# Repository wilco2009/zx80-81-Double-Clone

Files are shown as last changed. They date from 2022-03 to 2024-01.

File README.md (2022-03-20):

# PROJECT DOUBLE CLON ZX80/ZX81

Reading the works of [Grant Searle](http://searle.x10host.com/#ZX80), I have decided to start with the project to build a full computer to understand in depth his functionality. What can be more proper that a ZX80 totally based in discrete chips? 

In my spare time, I have started to work on it and you can find the results in the following lines.

I have copyied the schematics from the original zx80, and have made some modifications on it.

- I have added the extra circuitery to generate /NMI signal (Grant Searle Schematics), making possible to have two machines in one, by selecting it through a switch.
- Original 1K RAM in two chips have been replaced by one SRAM chip of  32KB.
- Original 4K ROM have been replaced by a EEPROM of 32KB. It necesary to store both ROMs (ZX80/ZX81) and it is cheaper than other smaller EPROMs.
-  RF modulator have been removed and replaced by a circuit to generate the standard back porch, missing in the original ZX80 PAL signal.

ZX80/81 Clone

The final result is nor a exact copy of the original as the case of Grant, but the board match accurately in the original case, and I very happy with the result.

## TECHNICAL & ASSEMBLY INFORMATION

In this project you can find the necesary information to build your own zx80. I think the most funny way to obtain your clon is to do it from zero, but if you wanna a clon and need the PCB or you have not enough knowledge or experience to assembly it, I have some spare PCBs and componentes, and I can sell them or assembly the clon for you. Please feel free to contact me and I'm sure we can reach an agreenment. ;)

Current version: 1.1

![](https://lh3.googleusercontent.com/rCJV6tn4bRtD5xP2J01XtbQhOAFcQkIHwjG2PTs5kUFLTJYEPpwRD9dPU9Wus_7P2roRMrFiV_r6bx4AB1eH3hhHG4VBcHm-jtsIfwT51LC9u5qDKVhMcgAC-uYpSRKtiEv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)

## JUMPER POSITION
JP1: RAMOE, Not relevant but must be present in one position
JP2:
              1-2 - Inverse Video
              2-3 - Standard Video
S2: ZX80/81 Mode selection (If you use external selection from the expansion board this jumper have to be removed)
              1-2 - ZX81 mode
              2-3 - ZX80 mode.

S4: Function of the Pin23B in the expansion bus. 
In original ZX80 pin 23B of the expansion bus is spare, but in a ZX81 PIN23B is use as /ROMCS signal.
If you want to use external zx81 mode selection form the expansion board you have to use position 1-2. In this case (in zx81 mode) cards replacing the internal ROM will not works.
If you prefer to use this kind of cards, you have to wire the zx81 selector (S2) directly to an accesible switch and set S4 in 2-3 position (remember to remove JP1 in the expansion board)
              1-2 - ZX81/ZX80 mode selection in PIN 23B
              2-3 - /ROMOE in PIN 23B

### Back porch Grant Searle solution:

              JP3 = 2-3
              JP5 = OFF
              JP6 = 1-2

### Back porch generation José Leandro solution:
              Adjust image with R37 & R33
              JP3 = 1-2
              JP5 = ON
              JP6 = 2-3

### Without Backporch generation (original ZX80 video)
              JP3 = 1-2
              JP5 = OFF
              JP6 = 1-2
              
## EXPANSION BOARD

This board has double functionality, first leaves enough room to connect zx81 cards  without trip with the video connector, and by other hand adds some extra functionality to the main board.


Expansion board let you to supply power to the computer with a miniUSB charger. If you plan to use external cards using 9V you will must to connect the computer to a 9V PS through the standard conector.
If you use the miniUSB supply, you could use the ON/OFF switch present in the board (S1) to turn on the computer.
S2 is a reset button, and it will works in any case.
JP7 Lets you to select ZX80/81 mode from the board if the position of the main jumper S4 is 1-2 and JP1 in the expansion board is ON.

JP1 Lets you aisle pin23B in the computer from the JP7 selector. It must be OFF if computer jumper S4 is 2-3.

![Clon working together with the ZXBlast](https://lh3.googleusercontent.com/j9ALMYmShmvCE-jy-AzifAf2zu_0noKhuHjYqihIMtmODiZwof2czWIUYXH-UqWGO6TdXiLnMDjAKpj7Po1c5WaS6kIWaJdyXEqjynNArSz48OjEJksTGsXhDxQqEvnr6YD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)

CONTACT: wilcoavs at gmail dot com



Update 01/02/2020.
Fix to resolve an incompatibility with some 74LS00s who inverts the screen. It is necessary to insert a 47K resistor between pin 1 and pin 14 of IC 11.

Update 17/02/2021 (many thanks to Augusto Baffa)
Quoted Augusto Baffa:
"My signal clock from IC18 PIN 9 was about (0-3v) and the High Pass Filter created by R25 and C11 was about (0-1v). It works on IC16 PIN 9 to generate the pulse that loads S/L on IC9 PIN 1 but was not working to load the latch'd on normal/inverse circuit 'cos IC11 pin 3 was always high.

So, after some testing I found that it's necessary to use another high pass filter to feed IC11 PIN2. I'm using a 100pF capacitor and a 3k6 resistor. After that it works fine. 



there is another item that could be improved. I've tested the Ear/cassete interface and it's producing a very low signal to IC10 PIN2.
 I analyzed the circuit on proteus and compared with original zx81 schematics and get the following:

Blue signal (it's dark... sorry)  is the signal produced by the original Searle's version. The red one is my propose in order to use the same PCB holes. and the green is the signal produced by the original zx81 circuit."



https://wilco2009.blogspot.com/2017/07/project-double-clon-zx80zx81-reading.html

## ACKNOLEDGEMENTS
- Jim Westwood - For designing the original machine
- Clive Sinclair - For introducing me in the computers world.
- Grant Searle - For his excellent work, he was the origin of mine. 
- Jose_Leandro, habbisoft - (in special way to jose_leandro) For helpping me in de debugging phase
- alvaroalea - For create an amaizing 3d printed case.
- carmeloco,flopping,sinclair200 - for supporting me in the initial phase

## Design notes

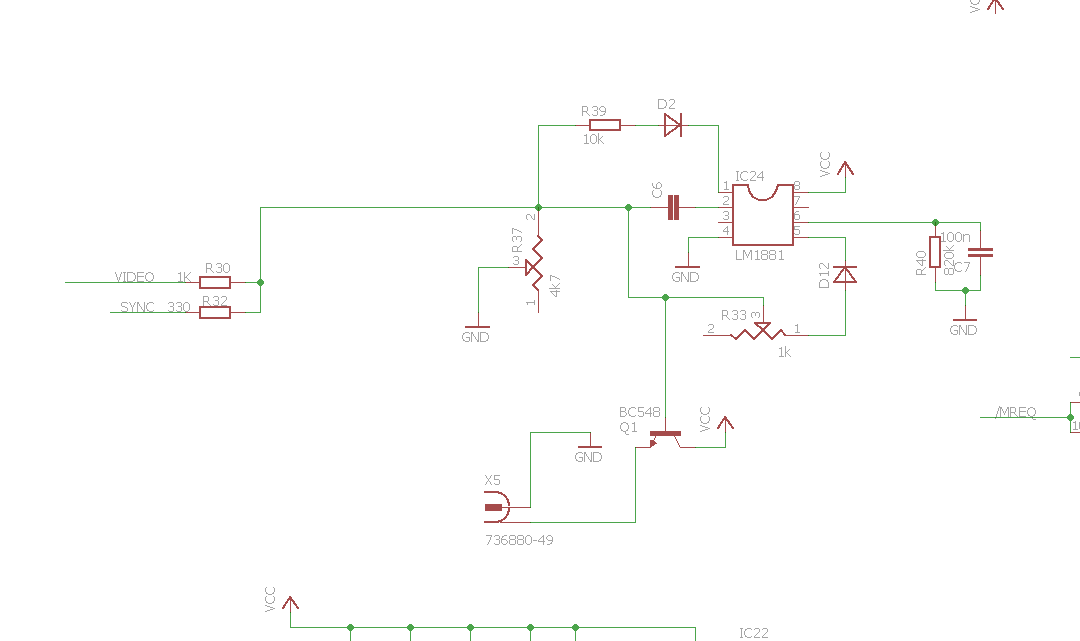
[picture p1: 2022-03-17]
doc/mod de video.png

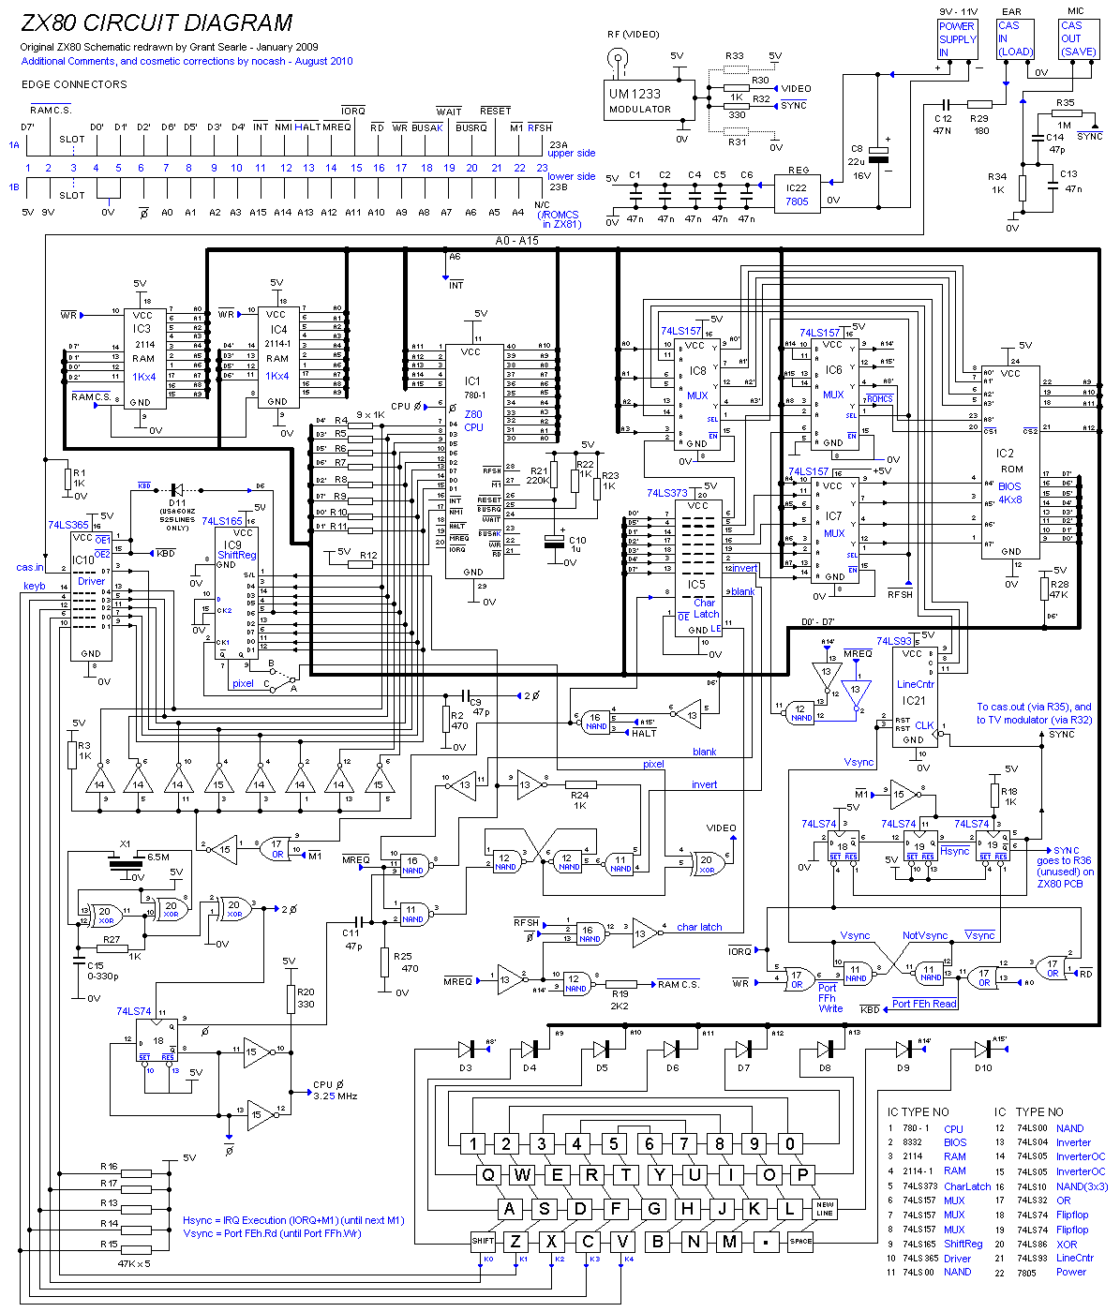
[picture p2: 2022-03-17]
doc/zx80-sch (original).gif

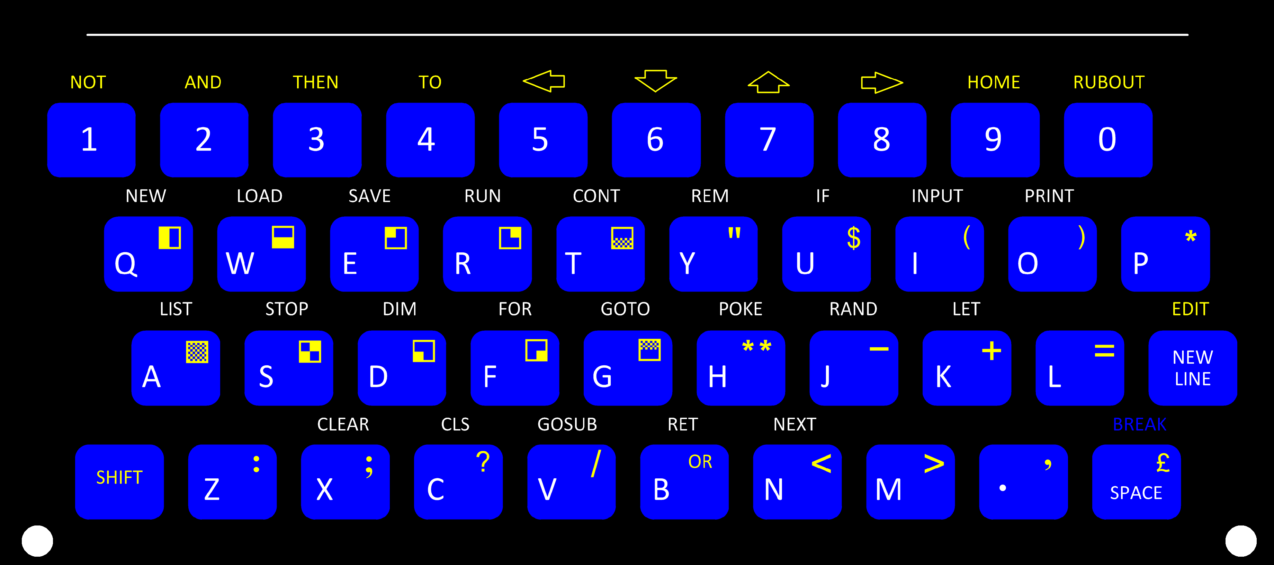
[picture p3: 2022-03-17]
Labels/Keyboard - zx80.png

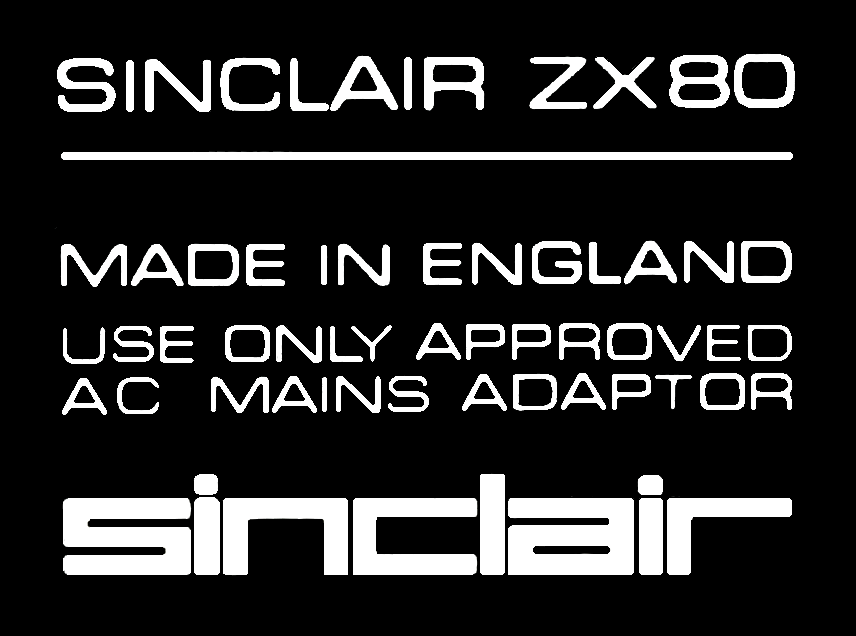
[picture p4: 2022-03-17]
Labels/made in england.png

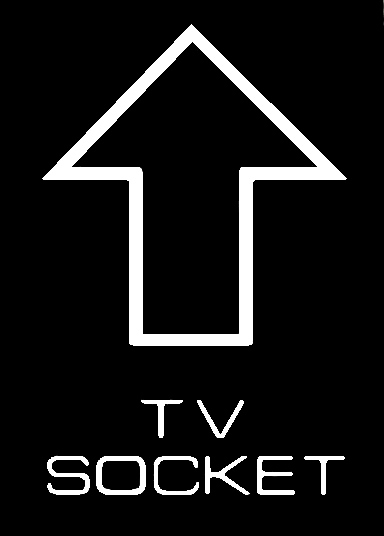
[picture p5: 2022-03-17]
Labels/tv socket.png

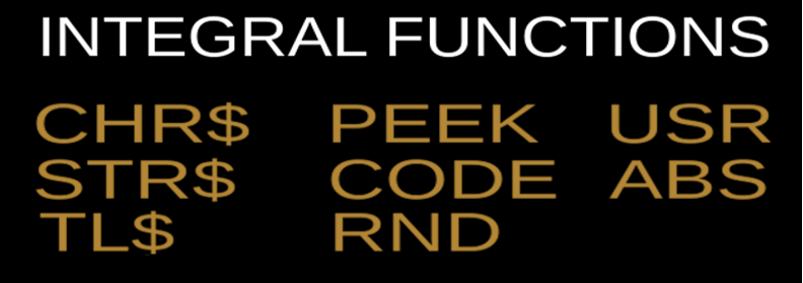
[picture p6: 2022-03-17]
Labels/ZX80 FUNCTIONS.png

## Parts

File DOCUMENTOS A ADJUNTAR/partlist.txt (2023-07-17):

Partlist

Exported from zx80_build039.routed.brd at 14/05/2023 19:09

EAGLE Version 9.6.2 Copyright (c) 1988-2020 Autodesk, Inc.

Assembly variant: 

Part     Value          Package      Library        Position (mm)         Orientation

.        TA_DK          TA_DK        dome-key       (124.46 10.16)        R0
1        TA_DK          TA_DK        dome-key       (10.16 52.705)        R0
1A                      EDGEPIN      wirepad        (10.16 200.025)       R0
1B                      EDGEPIN      wirepad        (10.16 200.025)       MR0
2        TA_DK          TA_DK        dome-key       (23.8125 52.705)      R0
2A                      EDGEPIN      wirepad        (12.7 200.025)        R0
2B                      EDGEPIN      wirepad        (12.7 200.025)        MR0
3        TA_DK          TA_DK        dome-key       (38.1 52.705)         R0
4        TA_DK          TA_DK        dome-key       (52.07 52.705)        R0
4A                      EDGEPIN      wirepad        (17.78 200.025)       R0
4B                      EDGEPIN      wirepad        (17.78 200.025)       MR0
5        TA_DK          TA_DK        dome-key       (66.04 52.705)        R0
5A                      EDGEPIN      wirepad        (20.32 200.025)       R0
5B                      EDGEPIN      wirepad        (20.32 200.025)       MR0
6        TA_DK          TA_DK        dome-key       (80.01 52.705)        R0
6A                      EDGEPIN      wirepad        (22.86 200.025)       R0
6B                      EDGEPIN      wirepad        (22.86 200.025)       MR0
7        TA_DK          TA_DK        dome-key       (93.98 52.705)        R0
7A                      EDGEPIN      wirepad        (25.4 200.025)        R0
7B                      EDGEPIN      wirepad        (25.4 200.025)        MR0
8        TA_DK          TA_DK        dome-key       (107.95 52.705)       R0
8A                      EDGEPIN      wirepad        (27.94 200.025)       R0
8B                      EDGEPIN      wirepad        (27.94 200.025)       MR0
9        TA_DK          TA_DK        dome-key       (121.92 52.705)       R0
9A                      EDGEPIN      wirepad        (30.48 200.025)       R0
9B                      EDGEPIN      wirepad        (30.48 200.025)       MR0
10A                     EDGEPIN      wirepad        (33.02 200.025)       R0
10B                     EDGEPIN      wirepad        (33.02 200.025)       MR0
11A                     EDGEPIN      wirepad        (35.56 200.025)       R0
11B                     EDGEPIN      wirepad        (35.56 200.025)       MR0
12A                     EDGEPIN      wirepad        (38.1 200.025)        R0
12B                     EDGEPIN      wirepad        (38.1 200.025)        MR0
13A                     EDGEPIN      wirepad        (40.64 200.025)       R0
13B                     EDGEPIN      wirepad        (40.64 200.025)       MR0
14A                     EDGEPIN      wirepad        (43.18 200.025)       R0
14B                     EDGEPIN      wirepad        (43.18 200.025)       MR0
15A                     EDGEPIN      wirepad        (45.72 200.025)       R0
15B                     EDGEPIN      wirepad        (45.72 200.025)       MR0
16A                     EDGEPIN      wirepad        (48.26 200.025)       R0
16B                     EDGEPIN      wirepad        (48.26 200.025)       MR0
17A                     EDGEPIN      wirepad        (50.8 200.025)        R0
17B                     EDGEPIN      wirepad        (50.8 200.025)        MR0
18A                     EDGEPIN      wirepad        (53.34 200.025)       R0
18B                     EDGEPIN      wirepad        (53.34 200.025)       MR0
19A                     EDGEPIN      wirepad        (55.88 200.025)       R0
19B                     EDGEPIN      wirepad        (55.88 200.025)       MR0
20A                     EDGEPIN      wirepad        (58.42 200.025)       R0
20B                     EDGEPIN      wirepad        (58.42 200.025)       MR0
21A                     EDGEPIN      wirepad        (60.96 200.025)       R0
21B                     EDGEPIN      wirepad        (60.96 200.025)       MR0
22A                     EDGEPIN      wirepad        (63.5 200.025)        R0
22B                     EDGEPIN      wirepad        (63.5 200.025)        MR0
23A                     EDGEPIN      wirepad        (66.04 200.025)       R0
23B                     EDGEPIN      wirepad        (66.04 200.025)       MR0
A        TA_DK          TA_DK        dome-key       (19.05 24.13)         R0
B        TA_DK          TA_DK        dome-key       (82.55 10.16)         R0
C        TA_DK          TA_DK        dome-key       (54.61 10.16)         R0
C1       47nF           C025-024X044 resistor       (38.1 132.08)         R180
C2       47nF           C025-024X044 resistor       (30.48 99.06)         R0
C3       47nF           C025-024X044 resistor       (15.24 99.06)         R180
C4       47nF           C025-024X044 resistor       (76.835 133.35)       R180
C5       47nF           C025-024X044 resistor       (152.0825 79.375)     R0
C6       100nF          C025-024X044 resistor       (139.7 99.06)         R180
C7       100pF          C025-024X044 resistor       (43.18 185.42)        R90
C8       22uF           E2,5-5       resistor       (12.7 189.23)         R0
C9       47pF           C050-024X044 resistor       (34.29 104.14)        R270
C10      1uF            E2,5-5       resistor       (74.93 144.78)        R0
C11      47pF           C025-024X044 resistor       (46.355 119.0625)     R0
C12      100nF          C025-024X044 resistor       (146.05 175.26)       R270
C13      47nF           C025-024X044 resistor       (123.19 186.69)       R180
C14      1nF            C025-024X044 resistor       (116.84 186.69)       R0
C15      220pF          C025-024X044 resistor       (145.7325 82.55)      R0
C16      47nF           C025-024X044 resistor       (125.73 148.59)       R90
C17      47nF           C025-024X044 resistor       (130.81 126.365)      R180
C18      10nF           C025-024X044 resistor       (146.05 181.61)       R270
C19      47nF           C025-024X044 resistor       (107.95 176.53)       R0
C20      47nF           C025-024X044 resistor       (118.11 126.365)      R0
C23      100uF          E2,5-5       resistor       (12.7 175.26)         R180
C24      100nF          C050-025X075 resistor       (60.96 148.59)        R90
C25      100pF          C025-024X044 resistor       (85.725 92.3925)      R90
C26      100pF          C050-024X044 resistor       (129.8575 97.4725)    R90
C27      470pf          C050-024X044 resistor       (118.11 104.14)       R180
CL0                     1,6/0,8      wirepad        (56.8325 66.9925)     R0
CL2                     1,6/0,8      wirepad        (17.4625 66.9925)     R0
CL3                     1,6/0,8      wirepad        (15.24 66.9925)       R0
CL4                     1,6/0,8      wirepad        (13.0175 66.9925)     R0
COL0                    1,6/0,8      wirepad        (109.22 76.835)       R0
COL1                    1,6/0,8      wirepad        (111.76 76.835)       R0
COL1'                   1,6/0,8      wirepad        (27.305 67.31)        R0
COL2                    1,6/0,8      wirepad        (114.3 76.835)        R0
COL3                    1,6/0,8      wirepad        (116.84 76.835)       R0
COL4                    1,6/0,8      wirepad        (119.38 76.835)       R0
D        TA_DK          TA_DK        dome-key       (48.26 24.4475)       R0
D1       1N4148DO35-7   DO35-7       diode          (133.35 187.96)       R0
D3       1N4148DO35-7   DO35-7       diode          (12.7 73.9775)        R180
D4       1N4148DO35-7   DO35-7       diode          (25.354640625 73.9775) R180
D5       1N4148DO35-7   DO35-7       diode          (38.00928125 73.9775) R180
D6       1N4148DO35-7   DO35-7       diode          (50.663921875 73.9775) R180
D7       1N4148DO35-7   DO35-7       diode          (63.3185625 73.9775)  R180
D8       1N4148DO35-7   DO35-7       diode          (75.973203125 73.9775) R180
D9       1N4148DO35-7   DO35-7       diode          (88.62784375 73.9775) R180
D10      1N4148DO35-7   DO35-7       diode          (101.282484375 73.9775) R180
D11      NTSC ONLY      DO35-7       diode          (27.94 133.6675)      R0
D13      1N4007         DO41-10      diode          (8.255 179.07)        R270
E        TA_DK          TA_DK        dome-key       (44.45 38.735)        R0
F        TA_DK          TA_DK        dome-key       (62.23 24.4475)       R0
G        TA_DK          TA_DK        dome-key       (76.2 24.4475)        R0
H        TA_DK          TA_DK        dome-key       (90.17 24.4475)       R0
I        TA_DK          TA_DK        dome-key       (114.3 38.735)        R0
IC1      Z80A           DIL40        zilog          (62.23 147.32)        R270
IC3      CY62256LL-PC   DIL28-6      memory-sram    (19.05 152.4)         R270
IC4      W27C512        DIL28        memory         (114.3 156.21)        R270
IC5      74S373N        DIL20        74xx-eu        (78.74 119.38)        R270
IC6      74157N         DIL16        74xx-eu        (95.25 163.83)        R270
IC7      74157N         DIL16        74xx-eu        (91.44 116.84)        R270
IC8      74157N         DIL16        74xx-eu        (81.28 163.83)        R270
IC9      74165N         DIL16        74xx-eu        (35.56 120.65)        R270
IC10     74LS365N       DIL16        74xx-eu        (19.05 120.65)        R270
IC11     74LS00N        DIL14        74xx-eu        (93.98 88.9)          R270
IC12     74LS00N        DIL14        74xx-eu        (107.95 88.9)         R270
IC13     74LS04N        DIL14        74xx-eu        (60.96 88.9)          R270
IC14     74LS05N        DIL14        74xx-eu        (15.24 88.9)          R270
IC15     74LS05N        DIL14        74xx-eu        (30.48 88.9)          R270
IC16     74LS10N        DIL14        74xx-eu        (45.72 88.9)          R270
IC17     74LS32N        DIL14        74xx-eu        (77.47 88.9)          R270
IC18     74LS74N        DIL14        74xx-eu        (122.555 88.5825)     R270
IC19     74LS74N        DIL14        74xx-eu        (105.41 115.57)       R270
IC20     74LS86N        DIL14        74xx-eu        (137.16 88.9)         R270
IC21     74LS93N        DIL14        74xx-eu        (96.52 142.24)        R270
IC22     7805T          TO220H       linear         (24.13 181.61)        R270
IC23     74LS00N        DIL14        74xx-eu        (116.84 115.57)       R270
J        TA_DK          TA_DK        dome-key       (104.14 24.4475)      R0
J1                      SPC4077      con-jack       (120.65 194.945)      R270
JP2      VIDEO_MODE     JP2          jumper         (57.15 113.03)        R90
K        TA_DK          TA_DK        dome-key       (118.11 24.4475)      R0
L        TA_DK          TA_DK        dome-key       (132.08 24.4475)      R0
M        TA_DK          TA_DK        dome-key       (110.49 10.16)        R0
N        TA_DK          TA_DK        dome-key       (96.52 10.16)         R0
O        TA_DK          TA_DK        dome-key       (135.89 52.705)       R0
O'       TA_DK          TA_DK        dome-key       (128.27 38.735)       R0
P        TA_DK          TA_DK        dome-key       (142.24 38.735)       R0
POWERLED RED            LED3MM       led            (17.78 105.41)        R180
Q        TA_DK          TA_DK        dome-key       (16.51 38.735)        R0
Q1       BC548          TO92-EBC     transistor-npn (41.91 177.8)         R180
R        TA_DK          TA_DK        dome-key       (58.42 38.735)        R0
R1       10K            0204/7       resistor       (19.05 132.08)        R180
R2       330            0204/7       resistor       (19.05 109.22)        R0
R3       1K             0204/7       resistor       (22.86 99.06)         R0
R4       1K             0204/7       resistor       (46.99 138.43)        R0
R5       1K             0204/7       resistor       (46.99 135.255)       R0
R6       1K             0204/7       resistor       (46.99 143.51)        R0
R7       1K             0204/7       resistor       (46.99 153.67)        R0
R8       1K             0204/7       resistor       (36.83 138.43)        R0
R9       1K             0204/7       resistor       (33.02 140.97)        R0
R10      1K             0204/7       resistor       (33.02 143.51)        R0
R11      1K             0204/7       resistor       (33.02 146.05)        R0
R12      1K             0204/7       resistor       (46.99 130.81)        R0
R13      47K            0204/7       resistor       (26.035 123.19)       R270
R14      47K            0204/7       resistor       (11.43 125.73)        R270
R15      47K            0204/7       resistor       (60.96 105.41)        R180
R16      47K            0204/7       resistor       (26.035 110.49)       R90
R17      47K            0204/7       resistor       (8.255 125.73)        R270
R18      1K             0204/7       resistor       (107.95 128.27)       R180
R19      2K2            0204/7       resistor       (115.8875 85.09)      R90
R20      330            0204/7       resistor       (46.99 158.75)        R180
R21      220K           0204/7       resistor       (78.74 187.96)        R180
R22      1K             0204/7       resistor       (69.85 115.57)        R270
R23      1K             0204/7       resistor       (46.99 128.27)        R180
R24      1K             0204/7       resistor       (86.36 82.55)         R270
R25      470            0204/7       resistor       (46.6725 114.3)       R0
R26      10K            0204/7       resistor       (40.64 187.96)        R270
R27      1K             0204/7       resistor       (145.415 90.17)       R90
R28      47K            0204/7       resistor       (53.34 91.44)         R90
R29      180            0204/7       resistor       (140.97 185.42)       R0
R30      900            0204/7       resistor       (96.52 196.85)        R180
R31      4k7            0204/7       resistor       (102.87 185.1025)     R0
R32      390            0204/7       resistor       (96.52 199.39)        R180
R33      4k7            0204/7       resistor       (102.87 182.5625)     R0
R34      1K             0204/7       resistor       (113.03 185.42)       R90
R35      100K           0204/7       resistor       (83.82 149.86)        R0
R36      2K7            0204/7       resistor       (130.81 185.42)       R180
R37      4k7            0204/7       resistor       (102.87 180.0225)     R0
R41      680            0204/7       resistor       (26.67 104.775)       R180
R42      680            0204/7       resistor       (139.7 104.14)        R180
R43      680            0204/7       resistor       (118.11 177.8)        R180
R45      330            0204/7       resistor       (81.915 100.6475)     R0
R46      680-6K8        0204/7       resistor       (130.175 87.9475)     R90
R47      0              0204/7       resistor       (129.2225 104.14)     R180
ROW0                    1,6/0,8      wirepad        (127 78.74)           R90
ROW1                    1,6/0,8      wirepad        (129.54 78.74)        R90
ROW2                    1,6/0,8      wirepad        (132.08 78.74)        R90
ROW3                    1,6/0,8      wirepad        (134.62 78.74)        R90
ROW4                    1,6/0,8      wirepad        (137.16 78.74)        R90
ROW5                    1,6/0,8      wirepad        (139.7 78.74)         R90
ROW6                    1,6/0,8      wirepad        (142.24 78.74)        R90
ROW7                    1,6/0,8      wirepad        (144.78 78.74)        R90
RW0                     1,6/0,8      wirepad        (46.99 66.9925)       R0
RW1                     1,6/0,8      wirepad        (34.12126875 67.31)   R0
RW2                     1,6/0,8      wirepad        (61.9125 66.9925)     R0
RW3                     1,6/0,8      wirepad        (21.59 67.31)         R0
RW4                     1,6/0,8      wirepad        (74.6125 66.9925)     R0
RW5                     1,6/0,8      wirepad        (8.5725 67.31)        R0
RW6                     1,6/0,8      wirepad        (85.09 66.9925)       R0
RW7                     1,6/0,8      wirepad        (97.4725 66.9925)     R0
S        TA_DK          TA_DK        dome-key       (34.29 24.4475)       R0
S1                      JP2          jumper         (11.43 105.41)        R90
S3       RESET          B3F-10XX     switch-omron   (106.68 192.405)      R180
S4       PIN23A         JP2          jumper         (120.015 181.2925)    R0
SHIFT    TA_DK          TA_DK        dome-key       (12.7 10.16)          R0
SPACE    TA_DK          TA_DK        dome-key       (138.43 10.16)        R0
SW1      TA_DK          TA_DK        dome-key       (146.05 24.13)        R0
SW2      ROM SEL        EDG-03       special        (92.3925 182.5625)    MR270
T        TA_DK          TA_DK        dome-key       (72.39 38.735)        R0
U        TA_DK          TA_DK        dome-key       (100.33 38.735)       R0
U1       74HC393N       DIL14        74xx-eu        (134.62 157.48)       R0
U2       74AC11N        DIL14        74xx-eu        (129.54 137.16)       R270
U3       74LS32N        DIL14        74xx-eu        (134.62 177.8)        R0
U4       74LS00N        DIL14        74xx-eu        (142.24 137.16)       R270
U5       74LS08N        DIL14        74xx-eu        (130.81 115.57)       R270
U6       74LS02N        DIL14        74xx-eu        (143.51 115.57)       R270
V        TA_DK          TA_DK        dome-key       (68.58 10.16)         R0
W        TA_DK          TA_DK        dome-key       (30.48 38.735)        R0
X        TA_DK          TA_DK        dome-key       (40.64 10.16)         R0
X2       EAR            PG203J       con-hirschmann (134.62 196.215)      R270
X3       MIC            PG203J       con-hirschmann (148.59 196.215)      R270
X4       POWER          PG203J       con-hirschmann (120.65 196.215)      R270
X5       736880-49      736880-49    con-conrad     (80.645 196.85)       R270
XTAL     6.5MHz         HC49U        crystal        (151.13 88.9)         R90
Y        TA_DK          TA_DK        dome-key       (86.36 38.735)        R0
Z        TA_DK          TA_DK        dome-key       (26.67 10.16)         R0
ZX81LED  YELLOW         LED3MM       led            (146.05 99.06)        R270

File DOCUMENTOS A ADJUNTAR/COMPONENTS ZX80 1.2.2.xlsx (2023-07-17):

Part |  | Value | Device | Package
C1..C5,C13,C16,C17,C19,C20 | 10 | 47nF | capacitor
C6,C12,C24 | 3 | 100nF | capacitor
C7,C25,C26 | 3 | 100pF | capacitor
C8 | 1 | 22uF | capacitor
C9,C11 | 2 | 47pF | capacitor
C14 | 1 | 1nF | capacitor
C10 | 1 | 1uF | capacitor
C15 | 1 | 220pF | capacitor
C18 | 1 | 10nF | capacitor
C23 | 1 | 100uF | capacitor
C27 | 1 | 470pf | capacitor
D1..D11 | 11 | 1N4148 | diode
D13 | 1 | 1N4007 | diode
IC1 | 1 | Z80A | CPU | DIP40
IC3 | 1 | 62256 | RAM | DIP28
IC4 | 1 | W27C512 | EEPROM | DIP28
IC5 | 1 | 74LS373N | 74xx | DIP20
IC6..IC8 | 3 | 74LS157N | 74xx | DIP16
IC9 | 1 | 74165N | 74xx | DIP16
IC10 | 1 | 74LS365N | 74xx | DIP16
IC11,IC12,IC23,U4 | 4 | 74LS00N | 74xx | DIP14
IC13 | 1 | 74LS04 | 74xx | DIP14
IC14,IC15 | 2 | 74LS05N | 74xx | DIP14
IC16 | 1 | 74LS10 | 74xx | DIP14
IC17,U3 | 2 | 74LS32N | 74xx | DIP14
IC18,IC19 | 2 | 74LS74N | 74xx | DIP14
IC20 | 1 | 74LS86N | 74xx | DIP14
IC21 | 1 | 74LS93N | 74xx | DIP14
IC23 | 1 | 7805 | 5V regulator | TO220
U1 | 1 | 74LS393N | 74xx | DIP14
U2 | 1 | 74LS11N | 74xx | DIP14
U5 | 1 | 74LS08N | 74xx | DIP14
U6 | 1 | 74LS02N | 74xx | DIP14
POWERLED | 1 | LED | RED | 3MM
ZX81LED | 1 | LED | BLUE | 3MM
Q1 | 1 | BC548 | transistor-npn | TO92
R1,R26 | 2 | 10K | resistor | 0204/7
R20 | 1 | 330R | resistor | 0204/7
R3..R12,R18,R22..R24,R27,R34 | 16 | 1K | resistor | 0204/7
R13..R17,R28, | 6 | 47K | resistor | 0204/7
R19 | 1 | 2K2 | resistor | 0204/7
R21 | 1 | 220K | resistor | 0204/7
R29 | 1 | 180R | resistor | 0204/7
R31,R33,R37 | 3 | 4K7 | resistor | 0204/7
R35 | 1 | 100K | resistor | 0204/7
R41..R43 | 3 | 680R | resistor | 0204/7
R47 | 1 | 0R | resistor | 0204/7
X2,X3,X4 | 3 | PG203J | FEMALE JACK | 3.5MM
JP2 | 1 | JUMPER | VIDEO_MODE
S1 | 1 | SWITCH | POWER SW
S3 | 1 | PUSH BUTTON | RESET
S4 | 1 | JUMPER | PIN23A
SW2 | 1 | DIPSWITCH-3 | ROM SEL
X5 | 1 | 736880-49 | VIDEO CONN
XTAL | 1 | 6.5MHZ | CRYSTAL
VARIABLE VALUES |  | DEFAULT | ADJUSTED
R2 |  | 330R
R25 |  | 470R
R45 |  | 470R
R46 |  | 680R
R47 |  | 680R
R30 |  | 1K
R32 |  | 330R
R36 |  | 2K7

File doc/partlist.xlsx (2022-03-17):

Partlist
C1 | 47nF | D9 | 1N4148 |  | JP5 | JP1E | jumper | R28 | 47K
C2 | 47nF | D10 | 1N4148 |  | JP6 | JP2E | jumper | R29 | 180
C3 | 47nF | D11 | 1N4148 | DO NOT INSTALL (NTSC ONLY) | POWERLED | RED | LED3MM | R30 | 1K
C4 | 47nF | D12 | 1N4148 |  | Q1 | BC548 | TO92-EBC | R31 | 10K
C5 | 47nF | D13 | 1N4007 |  | Q2 | BC548 | TO92-EBC | R32 | 330
C6 | 100nF | IC1 | Z80A | DIL40 | R1 | 1K |  | R33 | 1K
C7 | 100pF | IC2 | 27C128P/27C256/27C512 | DIL28-6 | R2 | 470 |  | R34 | 1K
C8 | 22uF | IC3 | CY62256LL-PC | DIL28-6 | R3 | 1K |  | R35 | 1M
C9 | 47pF | IC5 | 74S373N | DIL20 | R4 | 1K |  | R36 | 2K7
C10 | 1uF | IC6 | 74157N | DIL16 | R5 | 1K |  | R37 | 4K7
C11 | 47pF | IC7 | 74157N | DIL16 | R6 | 1K |  | R38 | 100
C12 | 47nF | IC8 | 74157N | DIL16 | R7 | 1K |  | R39 | 10k
C13 | 47nF | IC9 | 74165N | DIL16 | R8 | 1K |  | R40 | 820k
C14 | 47pF | IC10 | 74LS365N | DIL16 | R9 | 1K |  | R41 | 680
C15 | 220pF | IC11 | 74LS00N | DIL14 | R10 | 1K |  | R42 | 680
C16 | 47nF | IC12 | 74LS00N | DIL14 | R11 | 1K |  | R43 | 680
C17 | 47nF | IC13 | 74LS04N | DIL14 | R12 | 1K |  | S1 | JP2E | jumper
C18 | 10nF | IC14 | 74LS05N | DIL14 | R13 | 47K |  | S2 | JP2E | jumper
C19 | 47nF | IC15 | 74LS05N | DIL14 | R14 | 47K |  | S3 | RESET | PUSH BUTTON
C20 | 47nF | IC16 | 74LS10N | DIL14 | R15 | 47K |  | S4 | JP2E | jumper
C21 | 100nF | IC17 | 74LS32N | DIL14 | R16 | 47K |  | U1 | 74HC393N | DIL14
C22 | 100n | IC18 | 74LS74N | DIL14 | R17 | 47K |  | U2 | 74AC11N | DIL14
C23 | 100uF | IC19 | 74LS74N | DIL14 | R18 | 1K |  | U3 | 74LS32N | DIL14
C24 | 100nF | IC20 | 74LS86N | DIL14 | R19 | 2K2 |  | U4 | 74LS00N | DIL14
D1 | 1N4148 | IC21 | 74LS93N | DIL14 | R20 | 330 |  | U5 | 74LS08N | DIL14
D2 | 1N4148 | IC22 | 7805T | TO220H | R21 | 220K |  | U6 | 74LS02N | DIL14
D3 | 1N4148 | IC23 | 74LS00N | DIL14 | R22 | 1K |  | X2 | EAR | PG203J
D4 | 1N4148 | IC24 | LM1881 | DIL08 | R23 | 1K |  | X3 | MIC | PG203J
D5 | 1N4148 | J1 | JACK-PLUG0 | SPC4077 | R24 | 1K |  | X4 | POWER | PG203J
D6 | 1N4148 | JP1 | JP2E | jumper | R25 | 470 |  | X5 | 736880-49 | 736880-49
D7 | 1N4148 | JP2 | VIDEO_MODE | jumper | R26 | 10K |  | XTAL | 6.5MHz | crystal
D8 | 1N4148 | JP3 | JP2E | jumper | R27 | 1K |  | ZX81LED | YELLOW | LED3MM

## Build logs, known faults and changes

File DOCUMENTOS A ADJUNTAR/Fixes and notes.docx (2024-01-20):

## RESISTOR VALUES

R47 is a 0-ohm resistor, so it's just a jumper. Solder a wire in that spot.

## A thick vertical band on the left of the screen (sometimes it can fill the screen) can be corrected by adjusting the value of R36.

R2 is labeled with a value of 470 ohm, but it is better to solder a resistor with a Little les value. 330 ohm or 270 ohms. (a resistor of 330 ohm is included in the kit instead).

R46 is labeled as 680 ohms but may have to be adjusted depending on some specific mounting circumstances.

If you experiment video troubles you can adjust the value of R2 and R47 installing a 1K potentiometer in R2 position and a 5K pot in R47.

Too low a value of R2 will result in a shaky display, while too high a value will result in garbled characters.

Too low a value of R47 will show a vertical bar in front of some inverted characters.

Use the following program to be able to adjust the pots:

10 FOR N = 0 TO 255

20 PRINT CHR$(N);” “;

30 NEXT N

Run the program and try to adjust the pots. When you find the correct values, you can measure the resistance and to change both pots with resistors

## JUMPERS and DIP SWITCH

### S4 JUMPER (S23A BEHAVIOR).

This jumper allows you to select the function of pin S23A of the expansion connector.

For better compatibility with ZX81 peripherals put this jumper in position 2-3, while for maximum compatibility with ZX80 peripherals remove the jumper.

### JP2 JUMPER (VIDEO MODE)

Position 2-3 will display black characters on a white background, while position 1-2 will display white characters on a black background.

### SW2 (DIP SWITCH)

Let’s select the active ROM.

Switch 1 will select ZX80/81 mode.

In the following table you can see the ROMs preinstalled:

#ROM | BIN | DESCRIPTION | ADDR | MODE

0 | 000 | zx80 | 0000 | ZX80
1 | 001 | aszmic (z80 assembler os) | 2000 | ZX81
2 | 010 | aszmic (z80 assembler os) | 4000 | ZX80
3 | 011 | zx81.edition1 | 6000 | ZX81
4 | 100 | zx81.edition2 | 8000 | ZX80
5 | 101 | zx81.edition2 | A000 | ZX81
6 | 110 | zx81.edition3 | C000 | ZX80
7 | 111 | zx81.edition3 | E000 | ZX81

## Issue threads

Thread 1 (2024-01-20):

Video Trouble

A-Small-Mice, 2024-01-20:
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

I have created a ZX80/81 clone using Build39 BoM, but the screen is not displaying correctly.

I tried replacing resistors R46 and R47 with different ones as documented in Fixes and notes.docx, but the issue persists.

One thing that concerns me is that I used 330-ohm and 1K-ohm resistors for R32 and R30 next to the RCA connector, respectively, instead of the recommended 390-ohm and 900-ohm resistors because I didn't have them available.

How can I resolve this issue?

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

wilco2009, 2024-01-20:
With some types of 74LS08 it is necessary to increase the value of R46, sometimes up to 6.5K.
Try replacing R46 with a 10K potentiometer and try to adjust it until the vertical black band disappears.

A-Small-Mice, 2024-01-20:
Thank you so much for responding so quickly.

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

I only had a 5k potentiometer, so I initially attempted to solve the issue with a 5k potentiometer. However, no matter how much I manipulated the potentiometer, the black bar on the left side of the screen did not disappear.

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

Finally, I tried soldering a 6.5k resistor, but the black bar still remains.

Actually, there is one more minor issue. The keyboard input is abnormal. It seems like only numbers are being input no matter what key I press. As I am not familiar with the zx80, I hope it's just a matter of my lack of experience with its operation.

A-Small-Mice, 2024-01-20:
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

Upon reviewing the circuit diagram, it appeared that the resistances of R30 and R32 were deeply correlated with the video output.

I carefully adjusted two 1K potentiometers to create resistors of 900 ohms and 390 ohms. After soldering them, upon looking at the screen, I feel that the image has become sharper than before. However, the black bar on the left still does not disappear.

wilco2009, 2024-01-20:
I am sorry, the correct resistor to correct this is R36

A-Small-Mice, 2024-01-21:
Your advice regarding the R36 resistor was very accurate!

In my case, the acceptable range for the R36 resistor was between 400Ω and 900Ω. The thick vertical black band on the left of the screen disappeared.

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

Now, I have moved on to the next step. I installed 1K and 5K potentiometers on R2 and R47, respectively.

By adjusting the R2 potentiometer, all characters are displayed without any garbled characters. However, no matter how much I adjust the R47 potentiometer, a small black bar in front of some characters does not disappear.

wilco2009, 2024-01-21:
Try to replacing  74LS00 with 74HC00.

A-Small-Mice, 2024-01-21:
I ordered multiple 74HC00s. I have to wait until Tuesday to actually install them...

Another question: It's indicated that 74157Ns should be installed in IC6-8, and 74165N in IC9. However, I used 74LS157Ns and 74LS165N instead. Could this be a problem?

wilco2009, 2024-01-21:
No, LS is ok

A-Small-Mice, 2024-01-21:
I am currently in the middle of the problem-solving process. To potentially help others, I am documenting the results of my attempts in the following table:

I live in an NTSC country.
 |VARIABLE VALUES|DEFAULT|ADJUSTED by me|RESULT
|:--------------:|:-----:|:------------:|:-------:|
|R2              |330R   |470R          |Solved the garbled character issue
|R46             |680R   |0-5K Potentiometer        |No apparent change
|R30             |1K     |330R          |Adjusted screen and character brightness
|R32             |330R   |680R          |Adjusted screen and character brightness
|R36             |2K7    |680R          |Solved the thick vertical black band issue
|D1              |PAL (When Not Installed)    |NTSC (When Installed)         |Corrected horizontal sync

I have used various TVs for problem-solving. Some older NTSC CRT TVs (e.g., Samsung TXD-1372) display incorrect horizontal sync when the diode is not installed in D1. However, TVs in regions that use both 50Hz and 60Hz, such as Japan (e.g., Panasonic TM-115VN), can correct horizontal sync by manipulating a button. Modern TVs from the 2010s (e.g., LG 28TK430D) seem to be capable of automatically distinguishing and accepting both PAL and NTSC signals.

A-Small-Mice, 2024-01-22:
After making adjustments according to Table 1, I tested various TVs and found a peculiar observation.

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
▲These pictures show the screens of a Samsung analog NTSC-exclusive TV.

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
▲These pictures show the screens of a Ryokosha analog black and white TV, supporting both 50Hz and 60Hz. The built-in filter performs very well, resulting in very sharp text.

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
▲A small black bar in front of the letter 'S' is observed.

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
▲These pictures show the screens of a Panasonic analog color TV, supporting both 50Hz and 60Hz, but requiring manual synchronization through a knob. Interestingly, when the background is white and the text is black, the garbled character issue is observed.

A-Small-Mice, 2024-01-22:
After making adjustments according to Table 1, I tested various TVs and found a peculiar observation.

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
▲These pictures show the screens of a Samsung analog NTSC-exclusive TV.

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
▲These pictures show the screens of a Ryokosha analog black and white TV, supporting both 50Hz and 60Hz. The built-in filter performs very well, resulting in very sharp text.

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
▲A small black bar in front of the letter 'S' is observed.

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
▲These pictures show the screens of a Panasonic analog color TV, supporting both 50Hz and 60Hz, but requiring manual synchronization through a knob. Interestingly, when the background is white and the text is black, the garbled character issue is observed.

A-Small-Mice, 2024-01-23:
I replaced all four 74LS00s on the ZX80 clone PCB with 74HC00s. Upon doing so, something that was not visible before caught my eye. Inverted characters are now displayed on the screen. It seems like the video issue has finally been completely resolved.

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

* Table 2

 |PART|DEFAULT|ADJUSTED|RESULT
|:--------------:|:-----:|:------------:|:-------:|
|R2              |330R   |470R          |Solved the garbled character issue
|R46             |680R   |5K Potentiometer        |No apparent change
|R30             |1K     |330R          |Adjusted screen and character brightness
|R32             |330R   |680R          |Adjusted screen and character brightness
|R36             |2K7    |680R          |Solved the thick vertical black band issue
|D1              |PAL (When Not Installed)    |NTSC (When Installed)         |Corrected horizontal sync
|IC11,12,23 & U4        |74LS00|74HC00|The Inverted characters are now displayed correctly

A-Small-Mice, 2024-02-10:
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

I purchased metal domes in bulk at a low price from China and finally received them. The metal domes worked well. I thought it was time to replace the potentiometers with resistors and proceeded to do so. After cleaning the PCB with alcohol and drying it well, the inverted characters are once again not displaying properly. I'm not sure what the exact cause is...

A-Small-Mice, 2024-02-19:
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

I have experienced many trials and errors in order to figure out why the inverted characters were being displayed incorrectly again. Ultimately, it was a very simple issue, and I solved the puzzle.

It became clear that the 74HC00 I previously succeeded with was actually an SN74HC00 HLF. The 23ARSSJF4 SN74HC00 doesn't function properly for some reason. Perhaps it's fake chip.

The important thing is that now all the problems have been resolved. I sincerely appreciate your assistance. Finally, I have created the following table.

* Table 3

 |PART|DEFAULT|ADJUSTED|RESULT
|:--------------:|:-----:|:------------:|:-------:|
|R2              |330R   |470R          |Solved the garbled character issue
|R46             |680R   |5K Potentiometer        |No apparent change
|R30             |1K     |330R          |Adjusted screen and character brightness
|R32             |330R   |680R          |Adjusted screen and character brightness
|R36             |2K7    |680R          |Solved the thick vertical black band issue
|D1              |PAL (When Not Installed)    |NTSC (When Installed)         |Corrected horizontal sync
|IC11,12,23 & U4        |74LS00|***SN74HC00 HLF***|The Inverted characters are now displayed correctly

galluslongus, 2024-04-11:
Thanks a lot for your detailed postings, that helped me a lot to find some issues on my two clones.
I guess the most critical ICs are the 7400. I tried a lot of them and swapped them around, now one clone is fully working, the other one have issues with Graphics mode Text. It shows just the left half invers. I have to troubleshoot more into it.

galluslongus, 2024-04-12:
The most failures coming from IC11 / 74(LS)00. I installed a Pot for R25 and R45 and changed the values for C11 to 30pF and C25 to 220pF.  Tuning the Pots gave me a working Device. I messured the Pots and changed them to the closest values so R25 bis 100 Ohm and R45 is 67 Ohm for me (47+20).
Turning the Pots gave me a half inverse K, a Black screen and a normal looking K cursor.
There must be a better solution for that, like that it  makes no sense.
That all on my 1.1 PCB
On my 1.2.3 PCB the screen looks fine but i cant typ in a program, coz the device crashes or reboots if i hit a key more then one time. especially in the lower Row, like X C V.
Any ideas?

wilco2009, 2024-04-13:
The problems with PCB 1.2.3 seem to be due to poor contact, either of a chip to its socket or poor soldering.
In the case of board 1.1 I have no prior references to an image like the one you attach, but I think that the problem should be solved by regulating one of the resistances indicated.
Could you take some photos of how the video changes when you adjust the potentiometers to different values?

galluslongus, 2024-04-13:
Thanks for your reply,

PCB 1.1 is fixed so far. The Screen issue came from a bad Oszillator/Crystal, the ground pin was broken...
I tweaked again a bit with Cap  C11/25 and Resistor R25/45 values and also tried 18 different 74LS00 / 74HC00 in position 11 and 12. Sometimes i had an inverse screen, sometimes the cursor was half inverse and also seeing a small line before the cursor. But for now it seems fine.
Now its time to try this one with a bunch of Software...

PCB 1.2.3 is well soldered and all ICs have good contact.
It seems the board revision have some problems with static surroundings. at least my one.
I used adhesive Tape to hold down the metal domes and more or less often i push a key the device crashes or reboots.
See attached pictures showing crash after pushing a keypad via metal domes.
That doesn't happens when i attach a ZX81 Keyboard via the Flex Cable, wich is strange.
I swapped every single IC with knowing good ones, also with the ones of my PCB 1.1

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

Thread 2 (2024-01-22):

ROM and Keyboard Trouble (Build39)

A-Small-Mice, 2024-01-22:
I would like to apologize for being completely unfamiliar with the ZX80.

* ROM Trouble
I have used multiROMzx80clone v1.2.2.bin. By manipulating the DIP switch SW2, I obtained the following results: ROM1, ROM2, ROM6 have issues and cannot be used. Is there a way to correct this issue?

|ROM|BIN|DESCRIPTION              |ADDR|MODE|TEST RESULT
|:-:|:-:|:-----------------------:|:--:|:--:|:---------:|
|0  |000|zx80                     |0000|ZX80|Characters displayed as squares
|1  |001|aszmic (z80 assembler os)|2000|ZX81|No issue
|2  |010|aszmic (z80 assembler os)|4000|ZX80|Diagonals are repeatedly displayed on the screen
|3  |011|zx81.edition1            |6000|ZX81|No issue
|4  |100|zx81.edition2            |8000|ZX80|No issue
|5  |101|zx81.edition2            |A000|ZX81|No issue
|6  |110|zx81.edition3            |C000|ZX80|Characters displayed as squares
|7  |111|zx81.edition3            |E000|ZX81|No issue

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

* Keyboard Trouble

I do not have a dedicated membrane keyboard sheet for the ZX80. Initially, when attempting to create a ZX80 clone, I thought it would be possible to process key inputs simply by touching the keyboard contacts with fingers. However, even when touching the keyboard contacts, key inputs do not register, or incorrect keys are input. Should I prepare a dedicated membrane keyboard sheet, or is it expected that key inputs should work correctly even without a membrane keyboard sheet?

A-Small-Mice, 2024-01-23:
Through repeated key input tests, I finally discovered a method to input according to my will. However, I can only input the numbers 1, 2, 3, 4, and 5. The keys that can be input when using the 001 ROM is as shown in the following picture.

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

I don't quite understand why this is happening. I hope to find a way to solve this issue.

wilco2009, 2024-01-23:
For a functional keyboard you need to add [metal domes](https://es.aliexpress.com/item/1005005975513518.html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).
Just put the metal domes in the place row by row and use adhesive tape to fix it like in the [picture](https://photos.app.goo.gl/fMSaSJgv2qG1uZE59)

A-Small-Mice, 2024-01-23:
Metal Dome Membrane Switch!

Until now, I have been pressing the keyboard contacts with my fingers, and now I realize that it is the wrong input method. I will have to wait until this Thursday to put your advice into practice. I have ordered 8.4mm metal dome membrane switches.

wilco2009, 2024-01-23:
Ups, 8.4mm is too small, better 12mm

A-Small-Mice, 2024-01-24:
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
This is my mistake. I only measured the width, and it turned out to be 8.4mm. I have re-purchased switches with a diameter of 12mm.

A-Small-Mice, 2024-01-24:
I attempted input using a tactile switch (inside the tactile switch is a very small metal dome) and the results were successful. Inputting with a tactile switch was quite challenging, but in any case, I finally managed to create a line of code with the ZX80. It should be said that the keyboard issue has been resolved for now.

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

A-Small-Mice, 2024-03-07:
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

Through your advice, I have created a 3D printable membrane and combined it with metal domes. It functions reasonably well. For precise input, accurate pressure needs to be applied to the exact position of the membrane, but I anticipate that this can be addressed by improving the design of the 3D model.

A-Small-Mice, 2024-03-07:
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

When using the given ROM, I found a significant issue in ZX80 mode. When executing the RUN command, the code should run and display the results on the screen, but sometimes the results are not displayed.

For example, even after creating the code 10 PRINT "QWERTY" and executing the RUN command, sometimes QWERTY may not be displayed on the screen.

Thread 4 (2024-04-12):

Screen issues

galluslongus, 2024-04-12:
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
Im running into issues like showing in the picture.
PCB is 1.1
I swapped every IC and checked every solder joint.

Closed 2024-05-19.

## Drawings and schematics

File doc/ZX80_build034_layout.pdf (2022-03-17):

01/07/2017 21:23 C:\Users\Alejandro\Documents\eagle\eagle\zx80\zx80_build034.routed.brd³,5mm | 3,5mm | 3,5mm 1 2 3 1 2 3

IC2

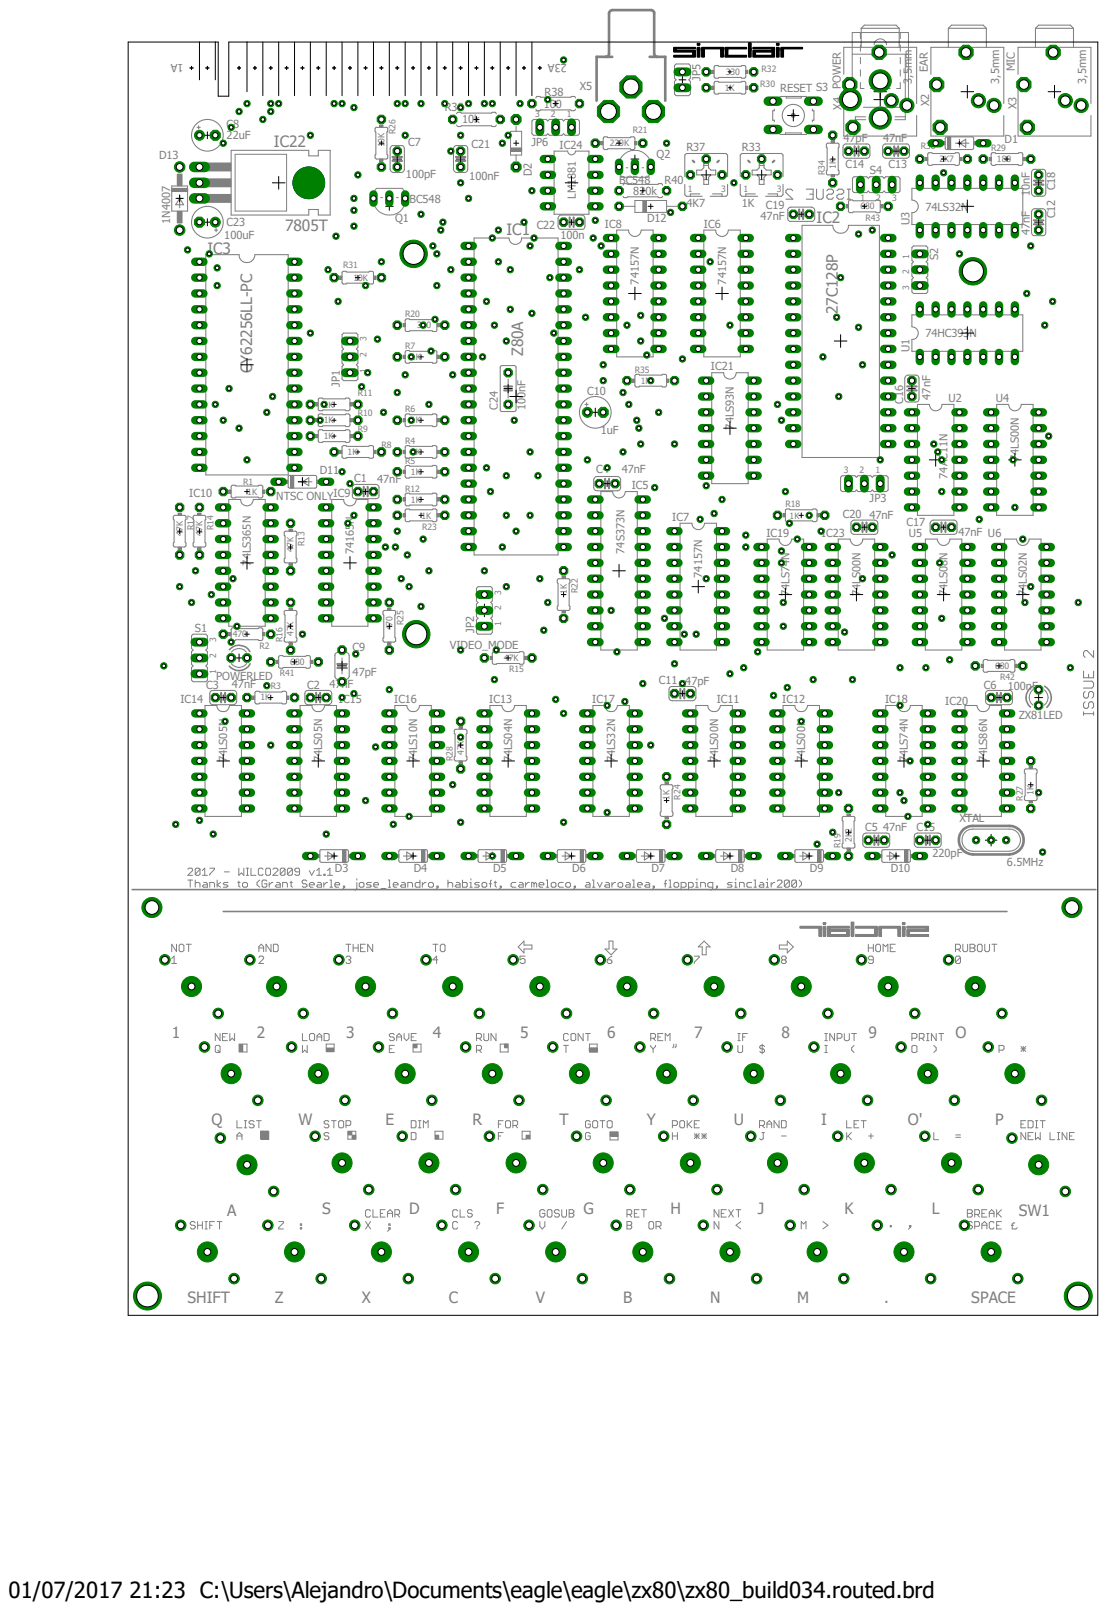
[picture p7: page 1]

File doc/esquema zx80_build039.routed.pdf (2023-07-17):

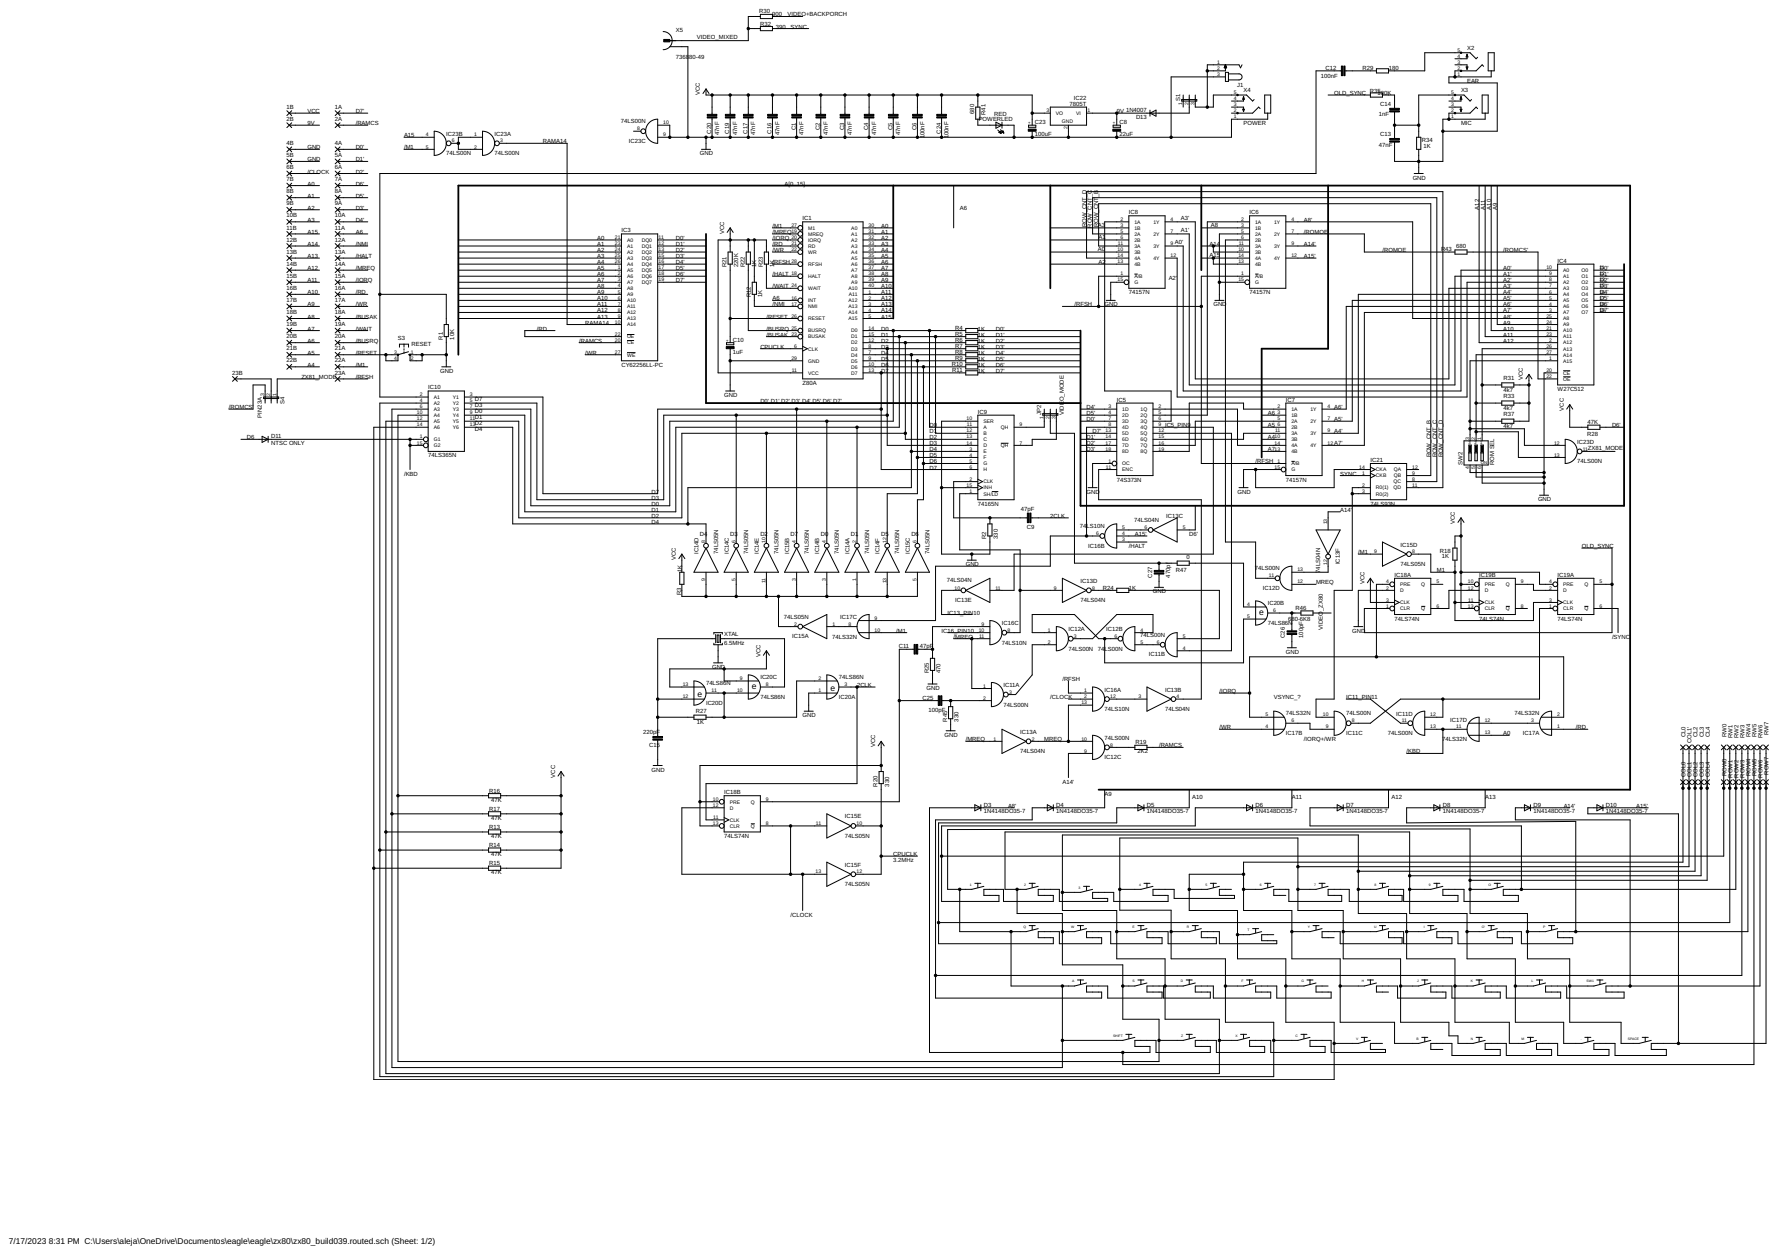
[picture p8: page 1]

7/17/2023 8:31 PM C:\Users\aleja\OneDrive\Documentos\eagle\eagle\zx80\zx80_build039.routed.sch (Sheet: 1/2)

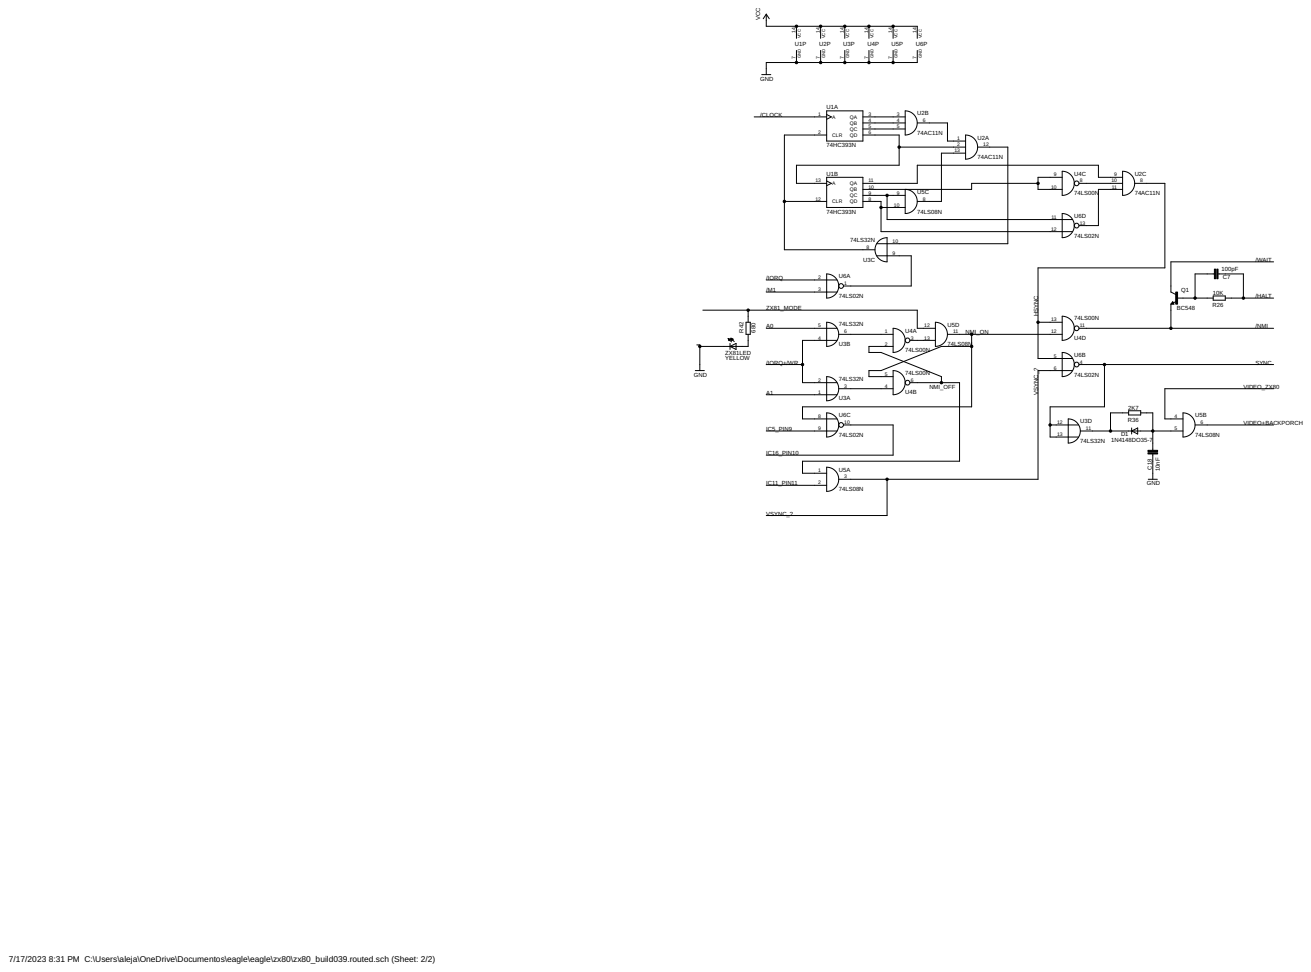
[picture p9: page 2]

7/17/2023 8:31 PM C:\Users\aleja\OneDrive\Documentos\eagle\eagle\zx80\zx80_build039.routed.sch (Sheet: 2/2)

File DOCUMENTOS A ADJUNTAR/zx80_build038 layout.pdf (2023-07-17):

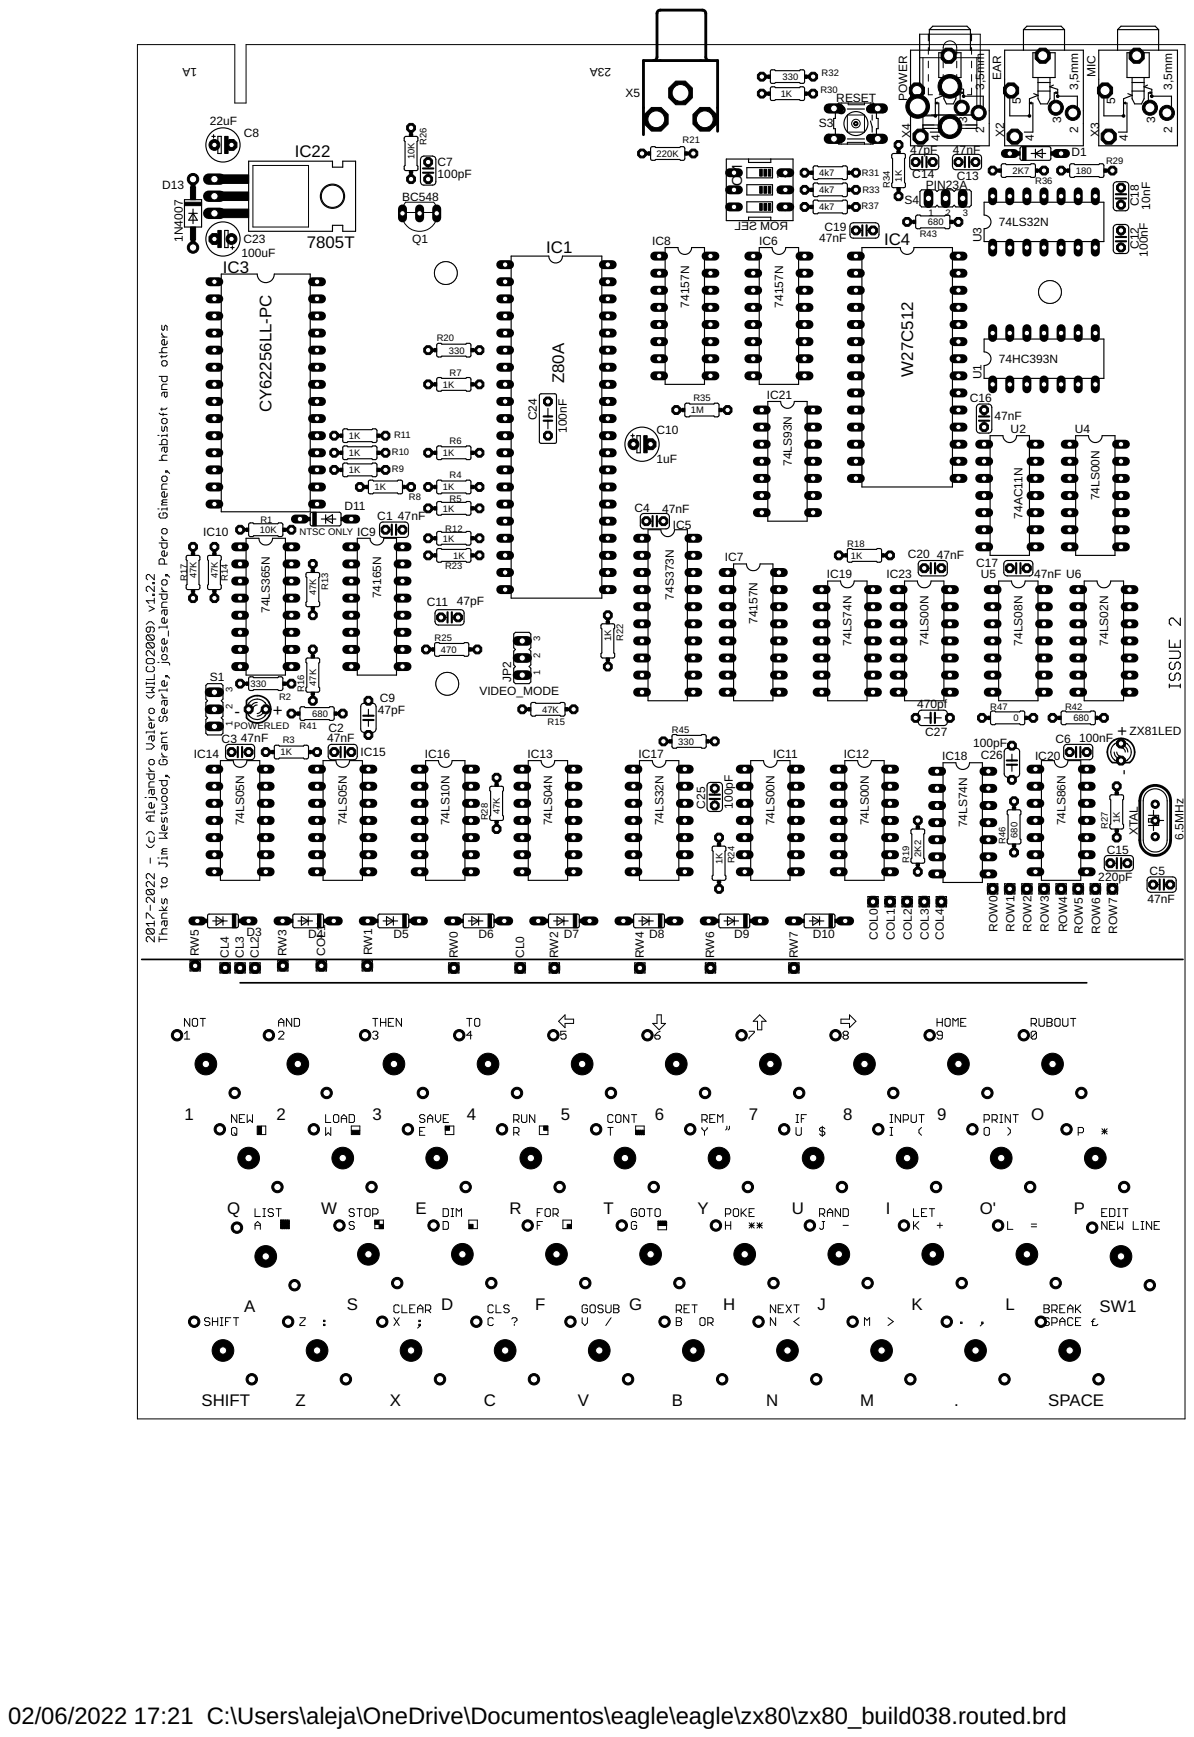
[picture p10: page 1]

02/06/2022 17:21 C:\Users\aleja\OneDrive\Documentos\eagle\eagle\zx80\zx80_build038.routed.brd

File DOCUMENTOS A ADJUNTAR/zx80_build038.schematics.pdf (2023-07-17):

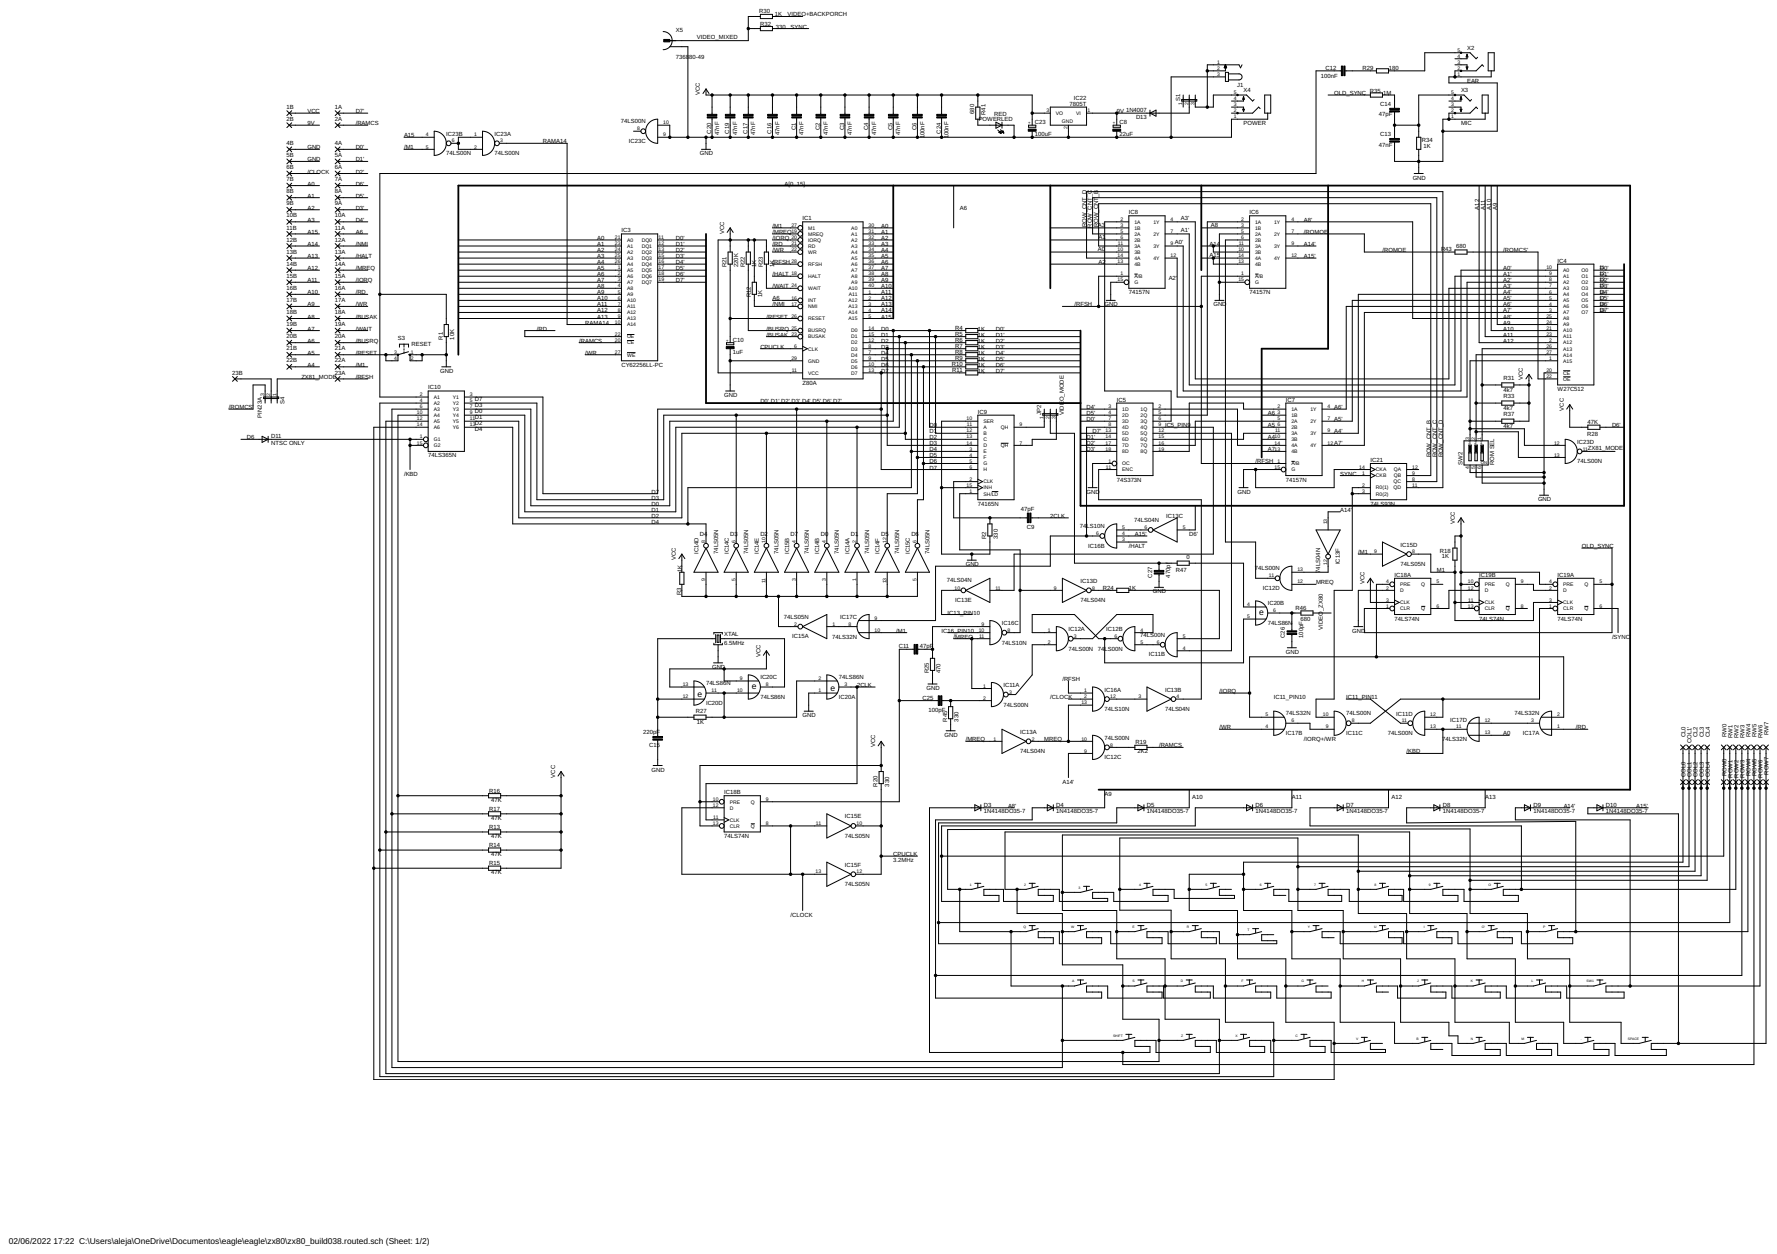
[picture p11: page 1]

02/06/2022 17:22 C:\Users\aleja\OneDrive\Documentos\eagle\eagle\zx80\zx80_build038.routed.sch (Sheet: 1/2)

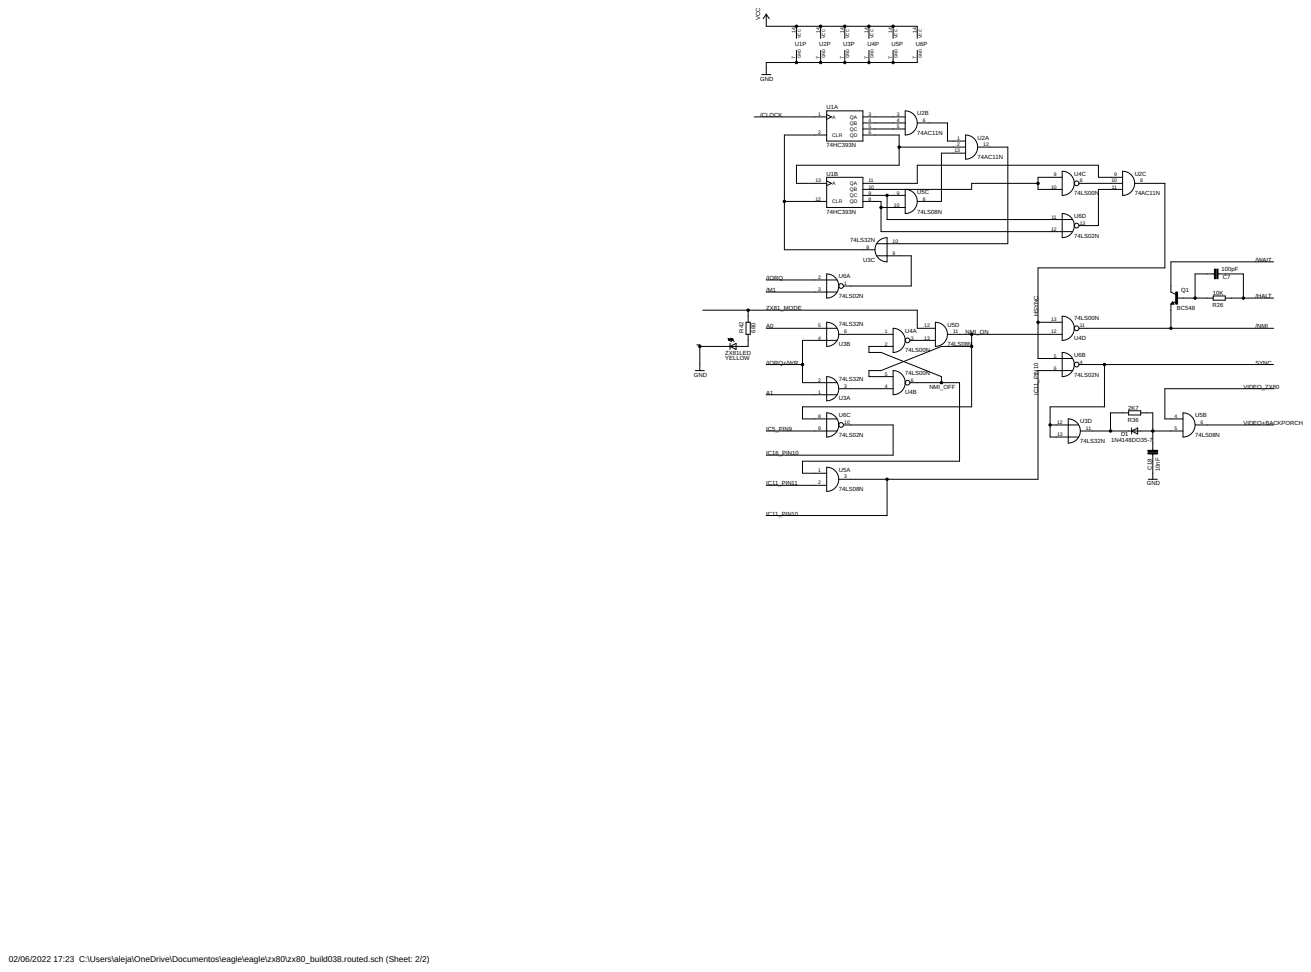
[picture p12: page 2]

02/06/2022 17:23 C:\Users\aleja\OneDrive\Documentos\eagle\eagle\zx80\zx80_build038.routed.sch (Sheet: 2/2)

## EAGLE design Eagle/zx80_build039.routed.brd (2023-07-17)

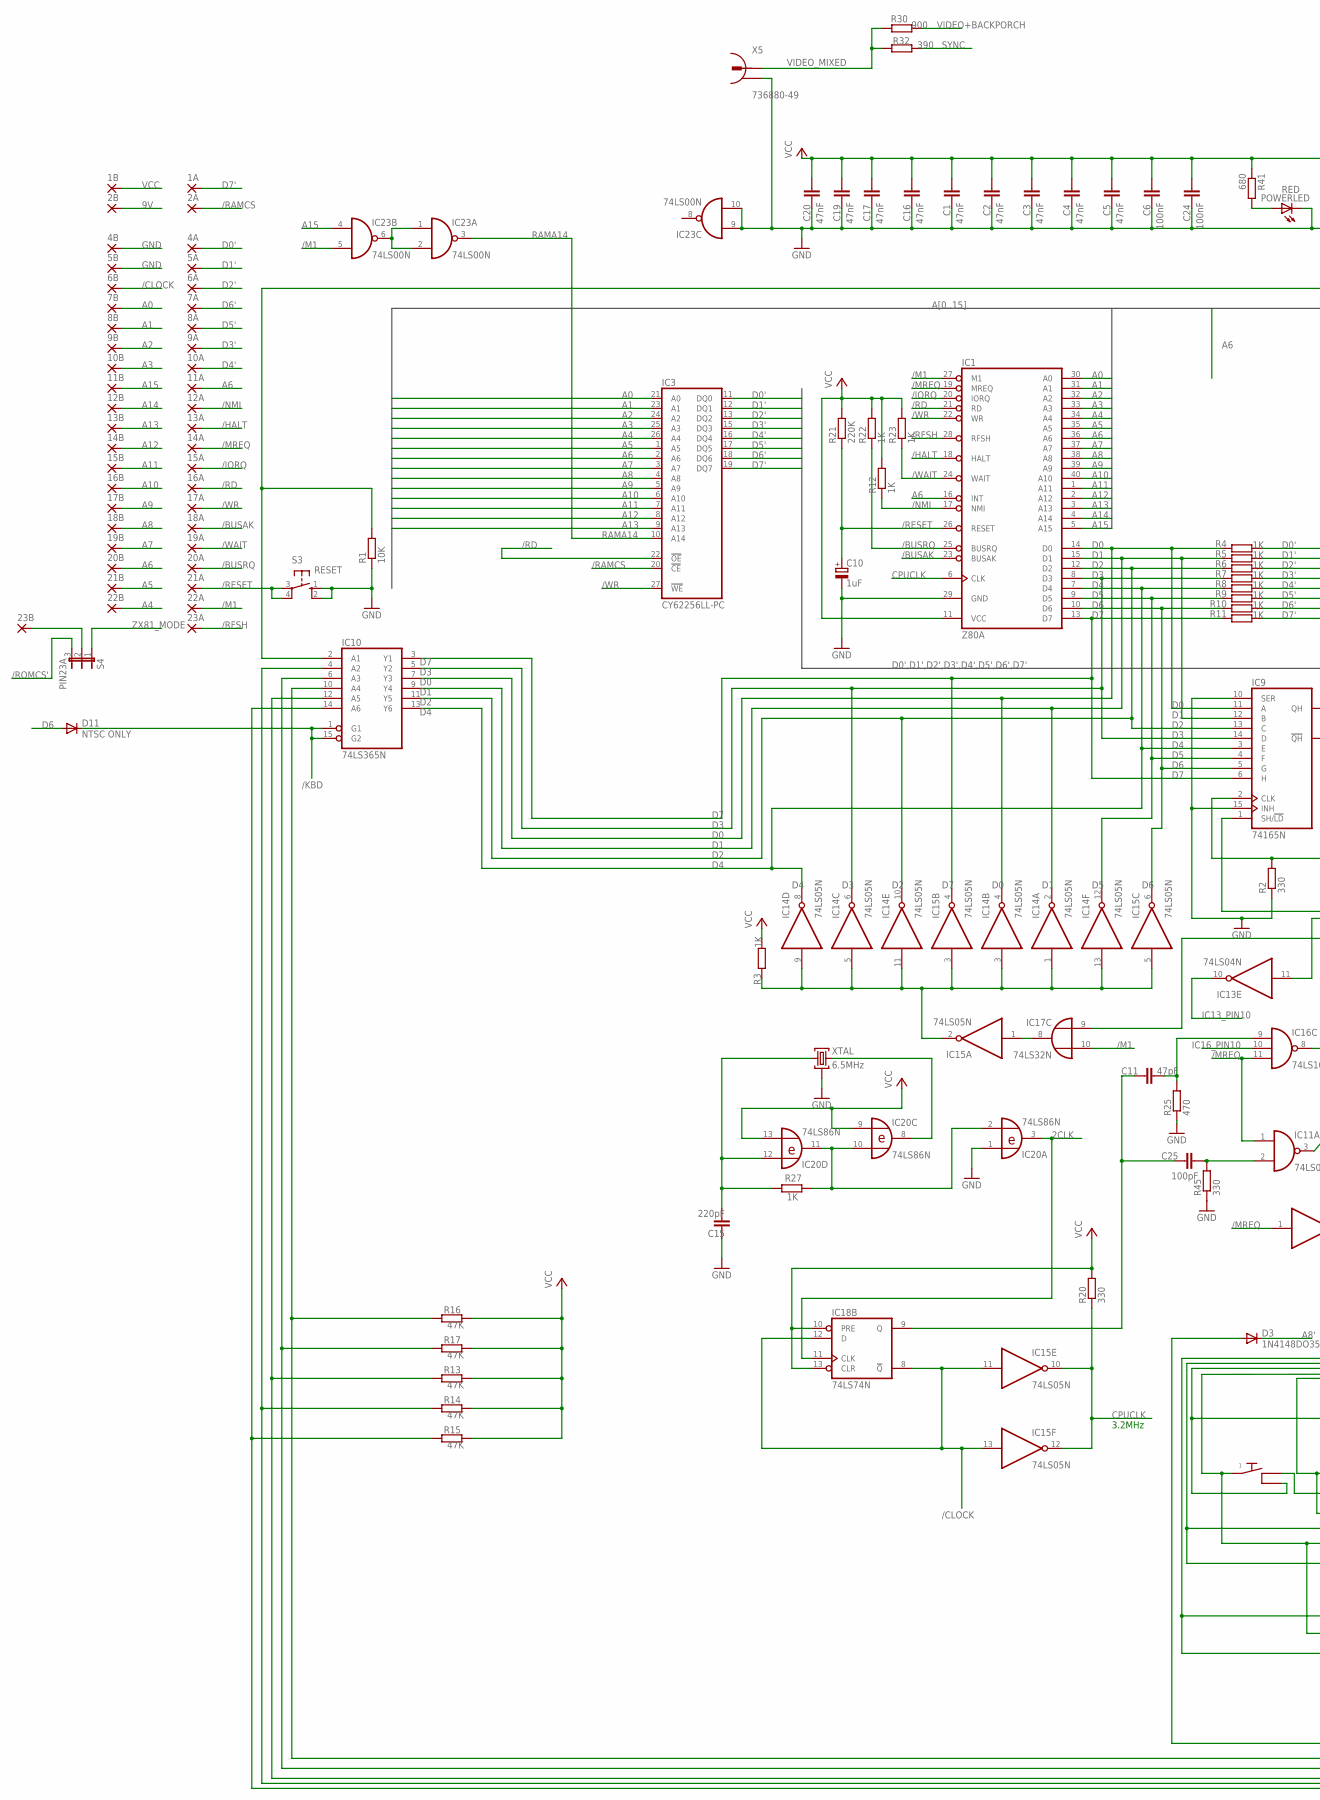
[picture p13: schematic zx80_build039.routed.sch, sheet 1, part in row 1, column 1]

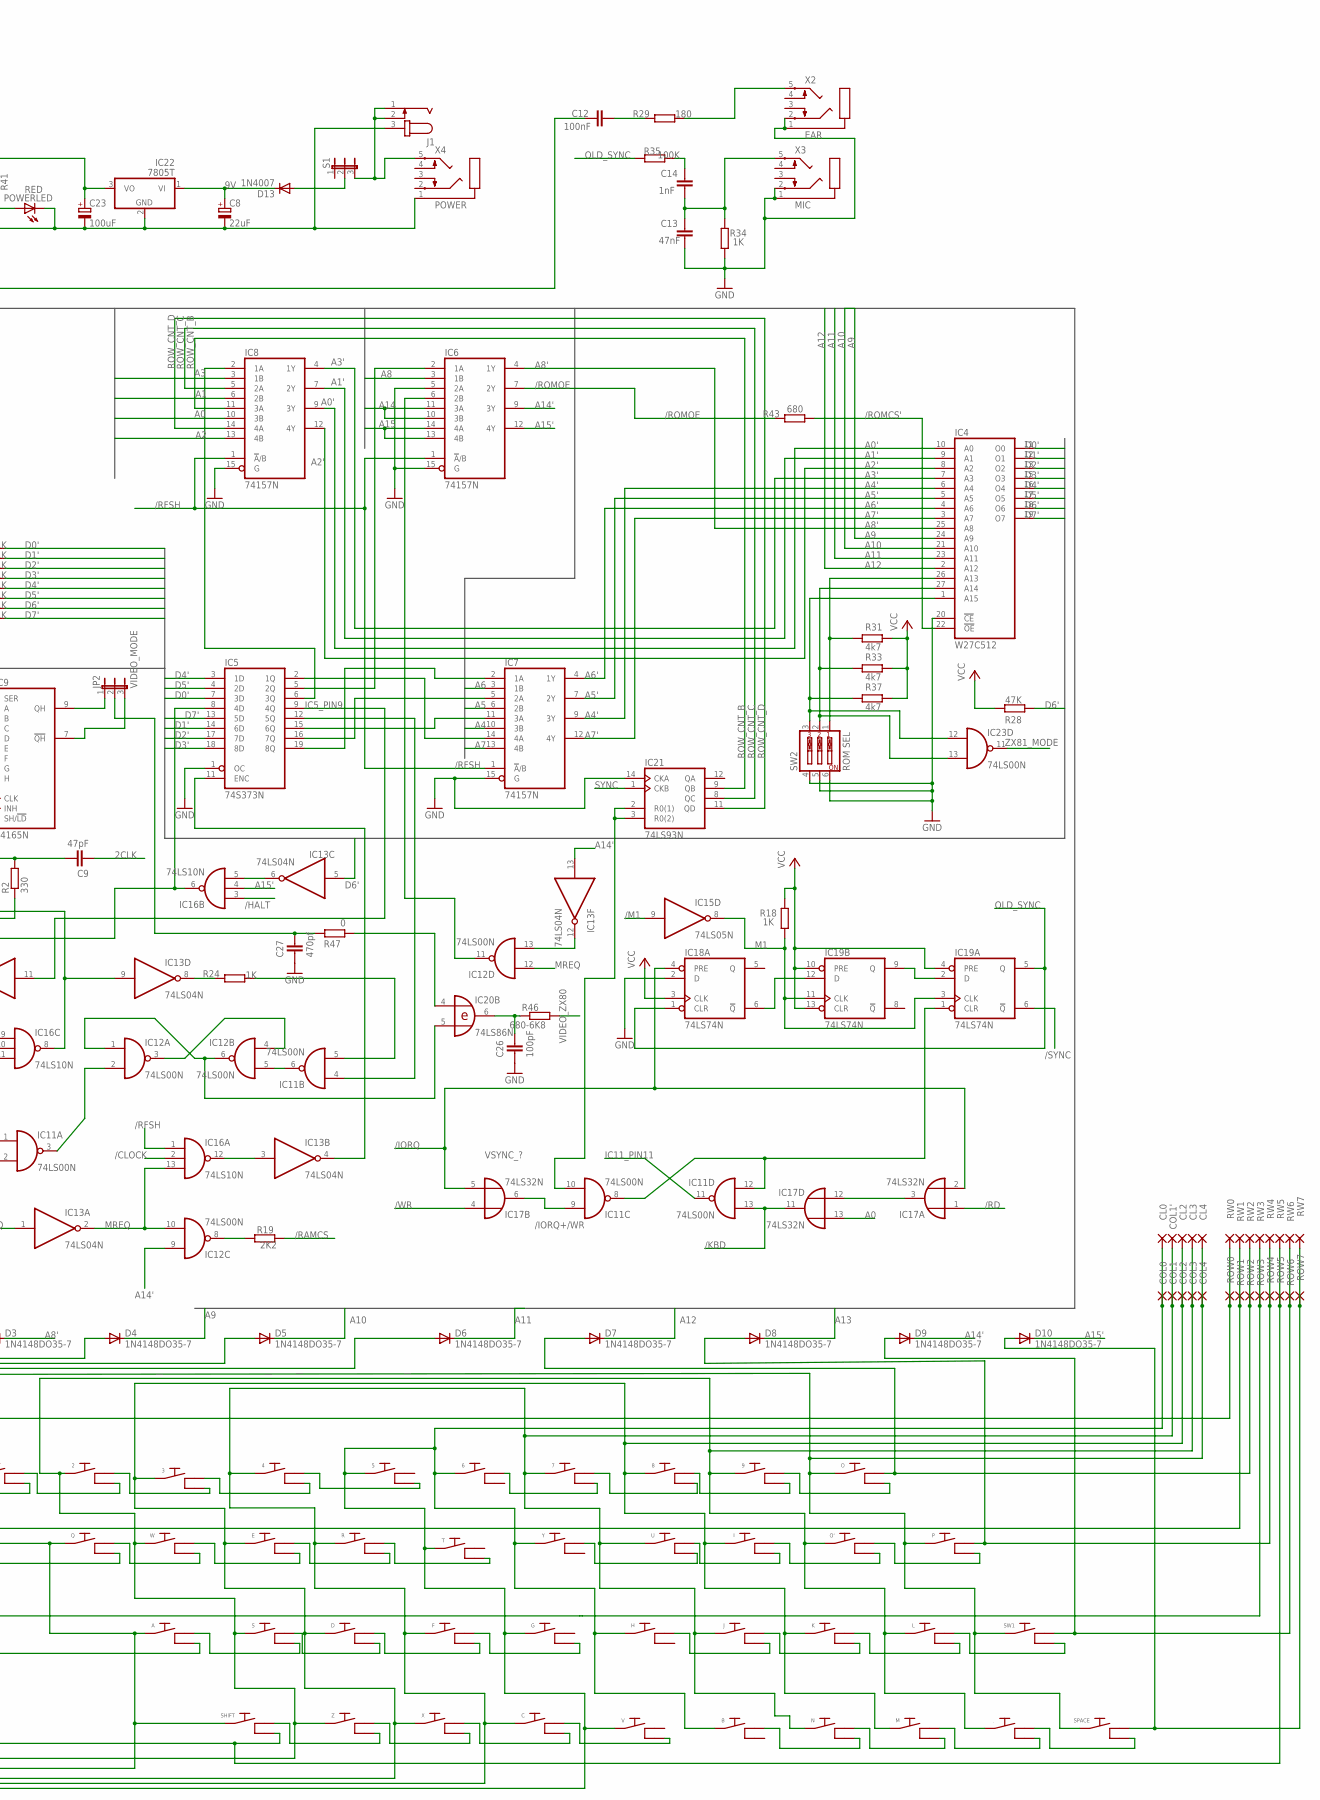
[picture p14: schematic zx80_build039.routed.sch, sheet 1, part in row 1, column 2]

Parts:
1, 2, 3, 4, 5, 6, 7, 8, 9, .: TA_DK
1A, 1B, 2A, 2B, 4A, 4B, 5A, 5B, 6A, 6B, 7A, 7B, 8A, 8B, 9A, 9B, 10A, 10B, 11A, 11B, 12A, 12B, 13A, 13B, 14A, 14B, 15A, 15B, 16A, 16B, 17A, 17B, 18A, 18B, 19A, 19B, 20A, 20B, 21A, 21B, 22A, 22B, 23A, 23B: SMD2EDGEPIN; EDGEPIN
A: TA_DK
B: TA_DK
C: TA_DK
C1, C2, C3, C4, C5, C13, C16, C17, C19, C20: 47nF; C025-024X044
C6, C12: 100nF; C025-024X044
C8: 22uF; E2,5-5
C9: 47pF; C050-024X044
C10: 1uF; E2,5-5
C11: 47pF; C025-024X044
C14: 1nF; C025-024X044
C15: 220pF; C025-024X044
C23: 100uF; E2,5-5
C24: 100nF; C050-025X075
C25: 100pF; C025-024X044
C26: 100pF; C050-024X044
C27: 470pf; C050-024X044
CL0, CL2, CL3, CL4: 1,6/0,8
COL0, COL1, COL1', COL2, COL3, COL4: 1,6/0,8
D: TA_DK
D3, D4, D5, D6, D7, D8, D9, D10: 1N4148DO35-7; DO35-7
D11: NTSC ONLY; DO35-7
D13: 1N4007; DO41-10
E: TA_DK
F: TA_DK
G: TA_DK
H: TA_DK
I: TA_DK
IC1: Z80A; DIL40
IC3: CY62256LL-PC; DIL28-6
IC4: W27C512; DIL28
IC5: 74S373N; DIL20
IC6, IC7, IC8: 74157N; DIL16
IC9: 74165N; DIL16
IC10: 74LS365N; DIL16
IC11, IC12, IC23: 74LS00N; DIL14
IC13: 74LS04N; DIL14
IC14, IC15: 74LS05N; DIL14
IC16: 74LS10N; DIL14
IC17: 74LS32N; DIL14
IC18, IC19: 74LS74N; DIL14
IC20: 74LS86N; DIL14
IC21: 74LS93N; DIL14
IC22: 7805T; TO220H
J: TA_DK
J1: JACK-PLUG0; SPC4077
JP2: VIDEO_MODE; JP2
K: TA_DK
L: TA_DK
M: TA_DK
N: TA_DK
O: TA_DK
O': TA_DK
P: TA_DK
POWERLED: RED; LED3MM
Q: TA_DK
R: TA_DK
R1: 10K; 0204/7
R2, R20, R45: 330; 0204/7
R3, R4, R5, R6, R7, R8, R9, R10, R11, R12, R18, R22, R23, R24, R27, R34: 1K; 0204/7
R13, R14, R15, R16, R17, R28: 47K; 0204/7
R19: 2K2; 0204/7
R21: 220K; 0204/7
R25: 470; 0204/7
R29: 180; 0204/7
R30: 900; 0204/7
R31, R33, R37: 4k7; 0204/7
R32: 390; 0204/7
R35: 100K; 0204/7
R41, R43: 680; 0204/7
R46: 680-6K8; 0204/7
R47: 0; 0204/7
ROW0, ROW1, ROW2, ROW3, ROW4, ROW5, ROW6, ROW7: 1,6/0,8
RW0, RW1, RW2, RW3, RW4, RW5, RW6, RW7: 1,6/0,8
S: TA_DK
S1: JP2E; JP2
S3: RESET; B3F-10XX
S4: PIN23A; JP2
SHIFT: TA_DK
SPACE: TA_DK
SW1: TA_DK
SW2: ROM SEL; EDG-03
T: TA_DK
U: TA_DK
V: TA_DK
W: TA_DK
X: TA_DK
X2: EAR; PG203J
X3: MIC; PG203J
X4: POWER; PG203J
X5: 736880-49
XTAL: 6.5MHz; HC49U
Y: TA_DK
Z: TA_DK

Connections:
2CLK: C9.2, IC18.11 (CLK), IC20.3 (O)
9V: 2B.1, C8.+, D13.C, IC22.1 (VI)
/BUSAK: 18A.1, IC1.23 (BUSAK)
/BUSRQ: 20A.1, IC1.25 (BUSRQ), R22.1
/CLOCK: 6B.1, IC15.11 (I), IC15.13 (I), IC16.2 (I1), IC18.8 (!Q), IC18.12 (D); also elsewhere on the board
/HALT: 13A.1, IC1.18 (HALT), IC16.3 (I0); also elsewhere on the board
/IORQ: 15A.1, IC1.20 (IORQ), IC17.2 (I1), IC17.5 (I1), IC18.4 (PRE); also elsewhere on the board
/IORQ+/WR: IC11.9 (I0), IC17.6 (O); also elsewhere on the board
/KBD: D11.C, IC10.1 (G1), IC10.15 (G2), IC11.13 (I1), IC17.11 (O)
/M1: 22A.1, IC1.27 (M1), IC15.9 (I), IC17.10 (I1), IC23.5 (I1); also elsewhere on the board
/MREQ: 14A.1, IC1.19 (MREQ), IC11.1 (I0), IC13.1 (I), IC16.11 (I2)
/NMI: 12A.1, IC1.17 (NMI), R12.1; also elsewhere on the board
/RAMCS: 2A.1, IC3.20 (!CE), R19.1
/RD: 16A.1, IC1.21 (RD), IC3.22 (!OE), IC17.1 (I0)
/RESET: 21A.1, C10.+, IC1.26 (RESET), R21.1, S3.3, S3.4 (P1)
/RFSH: 23A.1, IC1.28 (RFSH), IC6.1 (!A!/B), IC7.1 (!A!/B), IC8.1 (!A!/B), IC16.1 (I0)
/ROMCS': IC4.22 (!OE), R43.1, S4.3
/ROMOE: IC6.7 (2Y), R43.2
/SYNC: IC19.6 (!Q)
/WAIT: 19A.1, IC1.24 (WAIT), R23.1; also elsewhere on the board
/WR: 17A.1, IC1.22 (WR), IC3.27 (!WE), IC17.4 (I0)
A0: 7B.1, IC1.30 (A0), IC3.21 (A0), IC8.10 (3B), IC17.13 (I1); also elsewhere on the board
A0': IC4.10 (A0), IC8.9 (3Y)
A1: 8B.1, IC1.31 (A1), IC3.23 (A1), IC8.6 (2B); also elsewhere on the board
A1': IC4.9 (A1), IC8.7 (2Y)
A2: 9B.1, IC1.32 (A2), IC3.24 (A2), IC8.13 (4B)
A2': IC4.8 (A2), IC8.12 (4Y)
A3: 10B.1, IC1.33 (A3), IC3.25 (A3), IC8.3 (1B)
A3': IC4.7 (A3), IC8.4 (1Y)
A4: 22B.1, IC1.34 (A4), IC3.26 (A4), IC7.10 (3B)
A4': IC4.6 (A4), IC7.9 (3Y)
A5: 21B.1, IC1.35 (A5), IC3.1 (A5), IC7.6 (2B)
A5': IC4.5 (A5), IC7.7 (2Y)
A6: 11A.1, 20B.1, IC1.16 (INT), IC1.36 (A6), IC3.2 (A6), IC7.3 (1B)
A6': IC4.4 (A6), IC7.4 (1Y)
A7: 19B.1, IC1.37 (A7), IC3.3 (A7), IC7.13 (4B)
A7': IC4.3 (A7), IC7.12 (4Y)
A8: 18B.1, IC1.38 (A8), IC3.4 (A8), IC6.3 (1B)
A8': D3.C, IC4.25 (A8), IC6.4 (1Y)
A9: 17B.1, D4.C, IC1.39 (A9), IC3.5 (A9), IC4.24 (A9)
A10: 16B.1, D5.C, IC1.40 (A10), IC3.6 (A10), IC4.21 (A10)
A11: 15B.1, D6.C, IC1.1 (A11), IC3.7 (A11), IC4.23 (A11)
A12: 14B.1, D7.C, IC1.2 (A12), IC3.8 (A12), IC4.2 (A12)
A13: 13B.1, D8.C, IC1.3 (A13), IC3.9 (A13)
A14: 12B.1, IC1.4 (A14), IC6.10 (3B), IC6.11 (3A)
A14': D9.C, IC6.9 (3Y), IC12.9 (I0), IC13.13 (I)
A15: 11B.1, IC1.5 (A15), IC6.13 (4B), IC6.14 (4A), IC23.4 (I0)
A15': D10.C, IC6.12 (4Y), IC16.4 (I1)
CPUCLK: IC1.6 (CLK), IC15.10 (O), IC15.12 (O), R20.1
D0: IC1.14 (D0), IC9.11 (A), IC10.7 (Y3), IC14.4 (O), R4.2
D0': 4A.1, IC3.11 (DQ0), IC4.11 (O0), IC5.7 (3D), R4.1
D1: IC1.15 (D1), IC9.12 (B), IC10.9 (Y4), IC14.2 (O), R5.2
D1': 5A.1, IC3.12 (DQ1), IC4.12 (O1), IC5.14 (6D), R5.1
D2: IC1.12 (D2), IC9.13 (C), IC10.11 (Y5), IC14.10 (O), R6.2
D2': 6A.1, IC3.13 (DQ2), IC4.13 (O2), IC5.17 (7D), R6.1
D3: IC1.8 (D3), IC9.14 (D), IC10.5 (Y2), IC14.6 (O), R7.2
D3': 9A.1, IC3.15 (DQ3), IC4.15 (O3), IC5.18 (8D), R7.1
D4: IC1.7 (D4), IC9.3 (E), IC10.13 (Y6), IC14.8 (O), R8.2
D4': 10A.1, IC3.16 (DQ4), IC4.16 (O4), IC5.3 (1D), R8.1
D5: IC1.9 (D5), IC9.4 (F), IC14.12 (O), R9.2
D5': 8A.1, IC3.17 (DQ5), IC4.17 (O5), IC5.4 (2D), R9.1
D6: D11.A, IC1.10 (D6), IC9.5 (G), IC15.6 (O), R10.2
D6': 7A.1, IC3.18 (DQ6), IC4.18 (O6), IC13.5 (I), R10.1, R28.1
D7: IC1.13 (D7), IC9.6 (H), IC10.3 (Y1), IC15.4 (O), R11.2
D7': 1A.1, IC3.19 (DQ7), IC4.19 (O7), IC5.13 (5D), R11.1
GND: 4B.1, 5B.1, C1.2, C2.2, C3.2, C4.2, C5.2, C6.2, C8.-, C10.-, C13.2, C15.1, C16.2, C17.2, C19.2, C20.2, C23.-, C24.2, C26.2, C27.2, IC1.29 (GND), IC3.14 (GND), IC4.14 (GND), IC4.20 (!CE), IC5.1 (OC), IC5.10 (GND), IC6.5 (2A), IC6.8 (GND), IC6.15 (G), IC7.8 (GND), IC7.15 (G), IC8.8 (GND), IC8.15 (G), IC9.8 (GND), IC9.10 (SER), IC9.15 (INH), IC10.8 (GND), IC11.7 (GND), IC12.7 (GND), IC13.7 (GND), IC14.7 (GND), IC15.7 (GND), IC16.7 (GND), IC17.7 (GND), IC18.2 (D), IC18.7 (GND), IC19.7 (GND), IC20.1 (I0), IC20.7 (GND), IC21.10 (GND), IC21.14 (CKA), IC22.2 (GND), IC23.7 (GND), IC23.9 (I0), IC23.10 (I1), J1.3, POWERLED.K (C), R1.1, R2.1, R25.1, R34.2, R45.1, S3.1 (S), S3.2 (S1), SW2.4, SW2.5, SW2.6, X2.1, X2.2, X3.1, X3.2, X4.1, X5.1 (2), XTAL.2; also elsewhere on the board
IC5_PIN9: IC5.9 (4Q), IC13.11 (I); also elsewhere on the board
IC11_PIN11: IC11.11 (O); also elsewhere on the board
IC12_PIN11: IC6.6 (2B), IC12.11 (O)
IC13_PIN10: IC13.10 (O)
IC16_PIN10: IC16.10 (I1); also elsewhere on the board
M1: IC15.8 (O), IC19.3 (CLK), IC19.11 (CLK), R18.2
MREQ: IC12.10 (I1), IC12.12 (I0), IC13.2 (O), IC16.13 (I2)
unnamed: IC5.5 (2Q), IC6.2 (1A)
unnamed: J1.1, J1.2, S1.3, X4.5
unnamed: IC5.6 (3Q), IC8.2 (1A)
unnamed: IC5.2 (1Q), IC7.14 (4A)
unnamed: POWERLED.A, R41.2
unnamed: C9.1, IC9.2 (CLK), R2.2
unnamed: IC14.1 (I), IC14.3 (I), IC14.5 (I), IC14.9 (I), IC14.11 (I), IC14.13 (I), IC15.2 (O), IC15.3 (I), IC15.5 (I), R3.2
unnamed: IC4.27 (A14), IC23.13 (I1), R33.1, SW2.2
unnamed: IC4.26 (A13), R31.1, SW2.1
unnamed: 4.1, 7.1, C.1, COL1.1, COL1'.1, F.1, IC10.4 (A2), J.1, N.1, R.1, R14.2, U.1
unnamed: IC13.6 (O), IC16.5 (I2)
unnamed: IC5.8 (4D), IC16.6 (O), IC17.9 (I0)
unnamed: R29.1, X2.5
unnamed: IC15.1 (I), IC17.8 (O)
unnamed: U.2@8 (2), Y.2@1 (2)
unnamed: D5.A, Q.2@8 (2), ROW1.1, RW1.1
unnamed: C11.2, IC16.9 (I0), R25.2
unnamed: IC9.1 (SH/!LD), IC13.9 (I), IC16.8 (O)
unnamed: D10.A, ROW7.1, RW7.1, SPACE.2@1 (2)
unnamed: IC13.8 (O), R24.2
unnamed: 2.2@1 (2), 3.2@8 (2)
unnamed: IC11.3 (O), IC12.2 (I1)
unnamed: IC12.1 (I0), IC12.6 (O), IC20.5 (I1)
unnamed: IC12.3 (O), IC12.4 (I0)
unnamed: IC11.6 (O), IC12.5 (I1)
unnamed: IC11.5 (I1), R24.1
unnamed: IC5.12 (5Q), IC11.4 (I0)
unnamed: IC9.9 (QH), JP2.1
unnamed: IC9.7 (!QH), JP2.3
unnamed: 3.2@1 (2), 4.2@8 (2)
unnamed: IC12.13 (I1), IC13.12 (O)
unnamed: IC18.6 (!Q), IC19.12 (D)
unnamed: IC19.2 (D), IC19.9 (Q)
unnamed: IC4.1 (A15), IC23.12 (I0), R37.1, SW2.3
unnamed: IC11.8 (O), IC11.12 (I0), IC19.1 (CLR)
unnamed: IC13.3 (I), IC16.12 (O)
unnamed: IC17.3 (O), IC17.12 (I0)
unnamed: IC5.11 (ENC), IC13.4 (O)
unnamed: D3.A, ROW5.1, RW5.1, SHIFT.2@8 (2)
unnamed: IC12.8 (O), R19.2
unnamed: A.2@8 (2), D4.A, ROW3.1, RW3.1
unnamed: IC20.2 (I1), IC20.10 (I1), IC20.11 (O), R27.2
unnamed: C15.2, IC20.12 (I0), R27.1, XTAL.1
unnamed: IC20.8 (O), XTAL.3
unnamed: C27.1, JP2.2, R47.2
unnamed: 5.1, 6.1, B.1, CL0.1, COL0.1, G.1, H.1, IC10.14 (A6), R15.2, T.1, V.1, Y.1
unnamed: C12.2, IC10.2 (A1), R1.2
unnamed: C12.1, R29.2
unnamed: D13.A, S1.2
unnamed: C13.1, C14.2, R34.1, X3.5
unnamed: 3.1, 8.1, CL2.1, COL2.1, D.1, E.1, I.1, IC10.12 (A5), K.1, M.1, R13.2, X.1
unnamed: C14.1, R35.1
unnamed: 4.2@1 (2), 5.2@8 (2)
unnamed: 23B.1, S4.2
unnamed: C11.1, C25.1, IC18.9 (Q)
unnamed: D7.A, O.2@1 (2), ROW2.1, RW2.1
unnamed: C26.1, IC20.6 (O), R46.2
unnamed: IC20.4 (I0), R47.1
unnamed: 1.2@8 (2), D6.A, ROW0.1, RW0.1
unnamed: 1.2@1 (2), 2.2@8 (2)
unnamed: E.2@8 (2), W.2@1 (2)
unnamed: K.2@1 (2), L.2@8 (2)
unnamed: C25.2, IC11.2 (I1), R45.2
unnamed: Q.2@1 (2), W.2@8 (2)
unnamed: I.2@1 (2), O'.2@8 (2)
unnamed: C.2@8 (2), X.2@1 (2)
unnamed: C.2@1 (2), V.2@8 (2)
unnamed: J.2@1 (2), K.2@8 (2)
unnamed: D8.A, P.2@1 (2), ROW4.1, RW4.1
unnamed: H.2@1 (2), J.2@8 (2)
unnamed: A.2@1 (2), S.2@8 (2)
unnamed: I.2@8 (2), U.2@1 (2)
unnamed: D9.A, ROW6.1, RW6.1, SW1.2@1 (2)
unnamed: L.2@1 (2), SW1.2@8 (2)
unnamed: O'.2@1 (2), P.2@8 (2)
unnamed: 9.2@1 (2), O.2@8 (2)
unnamed: X.2@8 (2), Z.2@1 (2)
unnamed: ..2@1 (2), SPACE.2@8 (2)
unnamed: ..2@8 (2), M.2@1 (2)
unnamed: M.2@8 (2), N.2@1 (2)
unnamed: B.2@1 (2), N.2@8 (2)
unnamed: D.2@8 (2), S.2@1 (2)
unnamed: SHIFT.2@1 (2), Z.2@8 (2)
unnamed: D.2@1 (2), F.2@8 (2)
unnamed: F.2@1 (2), G.2@8 (2)
unnamed: E.2@1 (2), R.2@8 (2)
unnamed: R.2@1 (2), T.2@8 (2)
unnamed: 2.1, 9.1, ..1, CL3.1, COL3.1, IC10.10 (A4), L.1, O'.1, R16.2, S.1, W.1, Z.1
unnamed: 1.1, A.1, CL4.1, COL4.1, IC10.6 (A3), O.1, P.1, Q.1, R17.2, SHIFT.1, SPACE.1, SW1.1
unnamed: IC5.15 (6Q), IC7.11 (3A)
unnamed: IC5.16 (7Q), IC7.5 (2A)
unnamed: IC5.19 (8Q), IC7.2 (1A)
unnamed: IC23.1 (I0), IC23.2 (I1), IC23.6 (O)
unnamed: 6.2@1 (2), 7.2@8 (2)
unnamed: 7.2@1 (2), 8.2@8 (2)
unnamed: 8.2@1 (2), 9.2@8 (2)
OLD_SYNC: IC18.1 (CLR), IC19.5 (Q), R35.2
RAMA14: IC3.10 (A14), IC23.3 (O)
ROW_CNT_B: IC8.11 (3A), IC21.9 (QB)
ROW_CNT_C: IC8.5 (2A), IC21.8 (QC)
ROW_CNT_D: IC8.14 (4A), IC21.11 (QD)
SYNC: IC21.1 (CKB), R32.1; also elsewhere on the board
VCC: 1B.1, C1.1, C2.1, C3.1, C4.1, C5.1, C6.1, C16.1, C17.1, C19.1, C20.1, C23.+, C24.1, IC1.11 (VCC), IC3.28 (VCC), IC4.28 (VCC), IC5.20 (VCC), IC6.16 (VCC), IC7.16 (VCC), IC8.16 (VCC), IC9.16 (VCC), IC10.16 (VCC), IC11.14 (VCC), IC12.14 (VCC), IC13.14 (VCC), IC14.14 (VCC), IC15.14 (VCC), IC16.14 (VCC), IC17.14 (VCC), IC18.3 (CLK), IC18.10 (PRE), IC18.13 (CLR), IC18.14 (VCC), IC19.4 (PRE), IC19.10 (PRE), IC19.13 (CLR), IC19.14 (VCC), IC20.9 (I0), IC20.13 (I1), IC20.14 (VCC), IC21.5 (VCC), IC22.3 (VO), IC23.14 (VCC), R3.1, R12.2, R13.1, R14.1, R15.1, R16.1, R17.1, R18.1, R20.2, R21.2, R22.2, R23.2, R28.2, R31.2, R33.2, R37.2, R41.1; also elsewhere on the board
VIDEO+BACKPORCH: R30.1; also elsewhere on the board
VIDEO_MIXED: R30.2, R32.2, X5.2 (1)
VIDEO_ZX80: R46.1; also elsewhere on the board
VSYNC_?: IC11.10 (I1), IC21.2 (R0(1)), IC21.3 (R0(2)); also elsewhere on the board
ZX81_MODE: IC23.11 (O), S4.1; also elsewhere on the board

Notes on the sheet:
3.2MHz

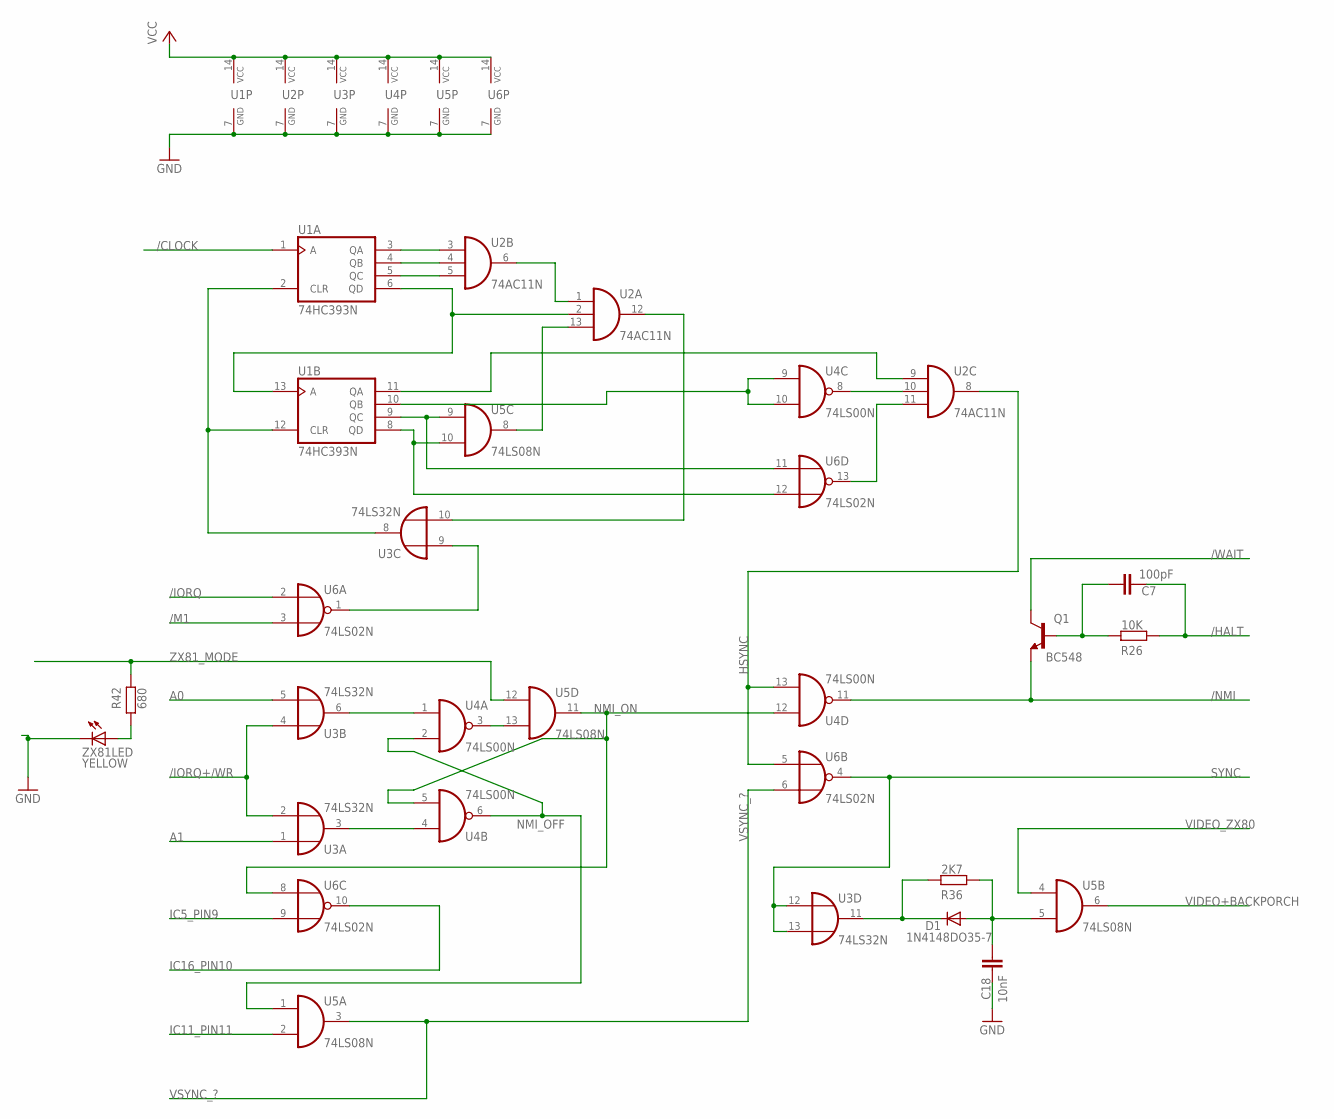
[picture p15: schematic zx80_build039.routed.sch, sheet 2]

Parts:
C7: 100pF; C025-024X044
C18: 10nF; C025-024X044
D1: 1N4148DO35-7; DO35-7
Q1: BC548; TO92-EBC
R26: 10K; 0204/7
R36: 2K7; 0204/7
R42: 680; 0204/7
U1: 74HC393N; DIL14
U2: 74AC11N; DIL14
U3: 74LS32N; DIL14
U4: 74LS00N; DIL14
U5: 74LS08N; DIL14
U6: 74LS02N; DIL14
ZX81LED: YELLOW; LED3MM

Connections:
/CLOCK: U1.1 (A); also elsewhere on the board
/HALT: C7.2, R26.1; also elsewhere on the board
/IORQ: U6.2 (I0); also elsewhere on the board
/IORQ+/WR: U3.2 (I1), U3.4 (I0); also elsewhere on the board
/M1: U6.3 (I1); also elsewhere on the board
/NMI: Q1.E, U4.11 (O); also elsewhere on the board
/WAIT: Q1.C; also elsewhere on the board
A0: U3.5 (I1); also elsewhere on the board
A1: U3.1 (I0); also elsewhere on the board
GND: C18.2, U1.7 (GND), U2.7 (GND), U3.7 (GND), U4.7 (GND), U5.7 (GND), U6.7 (GND), ZX81LED.K (C); also elsewhere on the board
HSYNC: U2.8 (O), U4.13 (I1), U6.5 (I0)
IC5_PIN9: U6.9 (I1); also elsewhere on the board
IC11_PIN11: U5.2 (I1); also elsewhere on the board
IC16_PIN10: U6.10 (O); also elsewhere on the board
unnamed: U3.9 (I0), U6.1 (O)
unnamed: C7.1, Q1.B, R26.2
unnamed: U1.3 (QA), U2.3 (I0)
unnamed: U1.4 (QB), U2.4 (I1)
unnamed: U1.5 (QC), U2.5 (I2)
unnamed: U2.1 (I0), U2.6 (O)
unnamed: U1.6 (QD), U1.13 (A), U2.2 (I1)
unnamed: U1.8 (QD), U5.10 (I1), U6.12 (I1)
unnamed: U1.10 (QB), U4.9 (I0), U4.10 (I1)
unnamed: U2.13 (I2), U5.8 (O)
unnamed: U2.12 (O), U3.10 (I1)
unnamed: U1.9 (QC), U5.9 (I0), U6.11 (I0)
unnamed: U1.11 (QA), U2.9 (I0)
unnamed: U1.2 (CLR), U1.12 (CLR), U3.8 (O)
unnamed: U2.10 (I1), U4.8 (O)
unnamed: U2.11 (I2), U6.13 (O)
unnamed: D1.C, R36.2, U3.11 (O)
unnamed: C18.1, D1.A, R36.1, U5.5 (I1)
unnamed: R42.1, ZX81LED.A
unnamed: U3.6 (O), U4.1 (I0)
unnamed: U3.3 (O), U4.4 (I0)
unnamed: U4.3 (O), U5.13 (I1)
NMI_OFF: U4.2 (I1), U4.6 (O), U5.1 (I0)
NMI_ON: U4.5 (I1), U4.12 (I0), U5.11 (O), U6.8 (I0)
SYNC: U3.12 (I0), U3.13 (I1), U6.4 (O); also elsewhere on the board
VCC: U1.14 (VCC), U2.14 (VCC), U3.14 (VCC), U4.14 (VCC), U5.14 (VCC), U6.14 (VCC); also elsewhere on the board
VIDEO+BACKPORCH: U5.6 (O); also elsewhere on the board
VIDEO_ZX80: U5.4 (I0); also elsewhere on the board
VSYNC_?: U5.3 (O), U6.6 (I1); also elsewhere on the board
ZX81_MODE: R42.2, U5.12 (I0); also elsewhere on the board

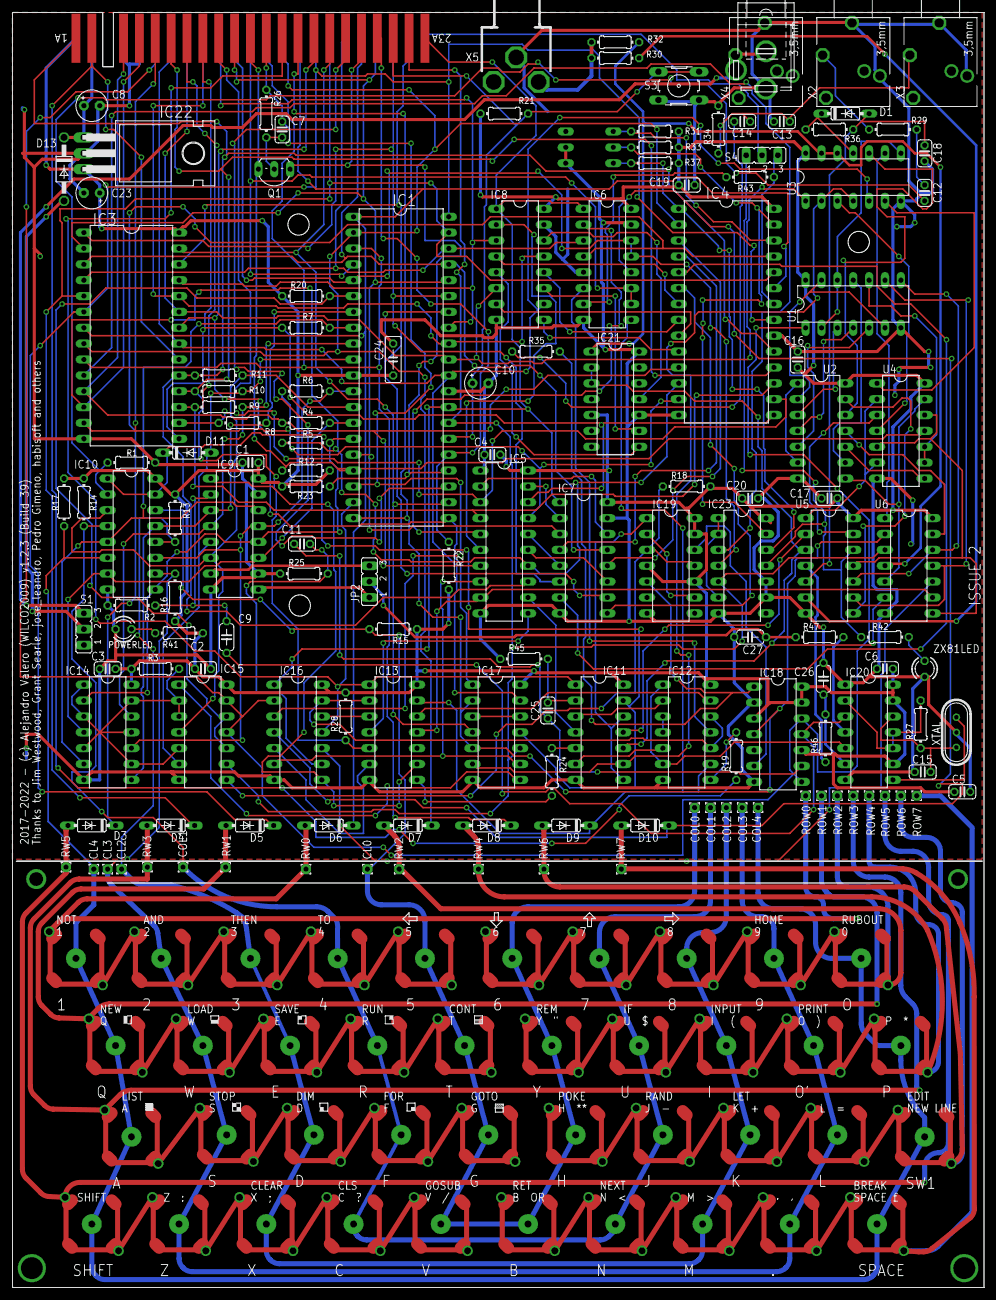
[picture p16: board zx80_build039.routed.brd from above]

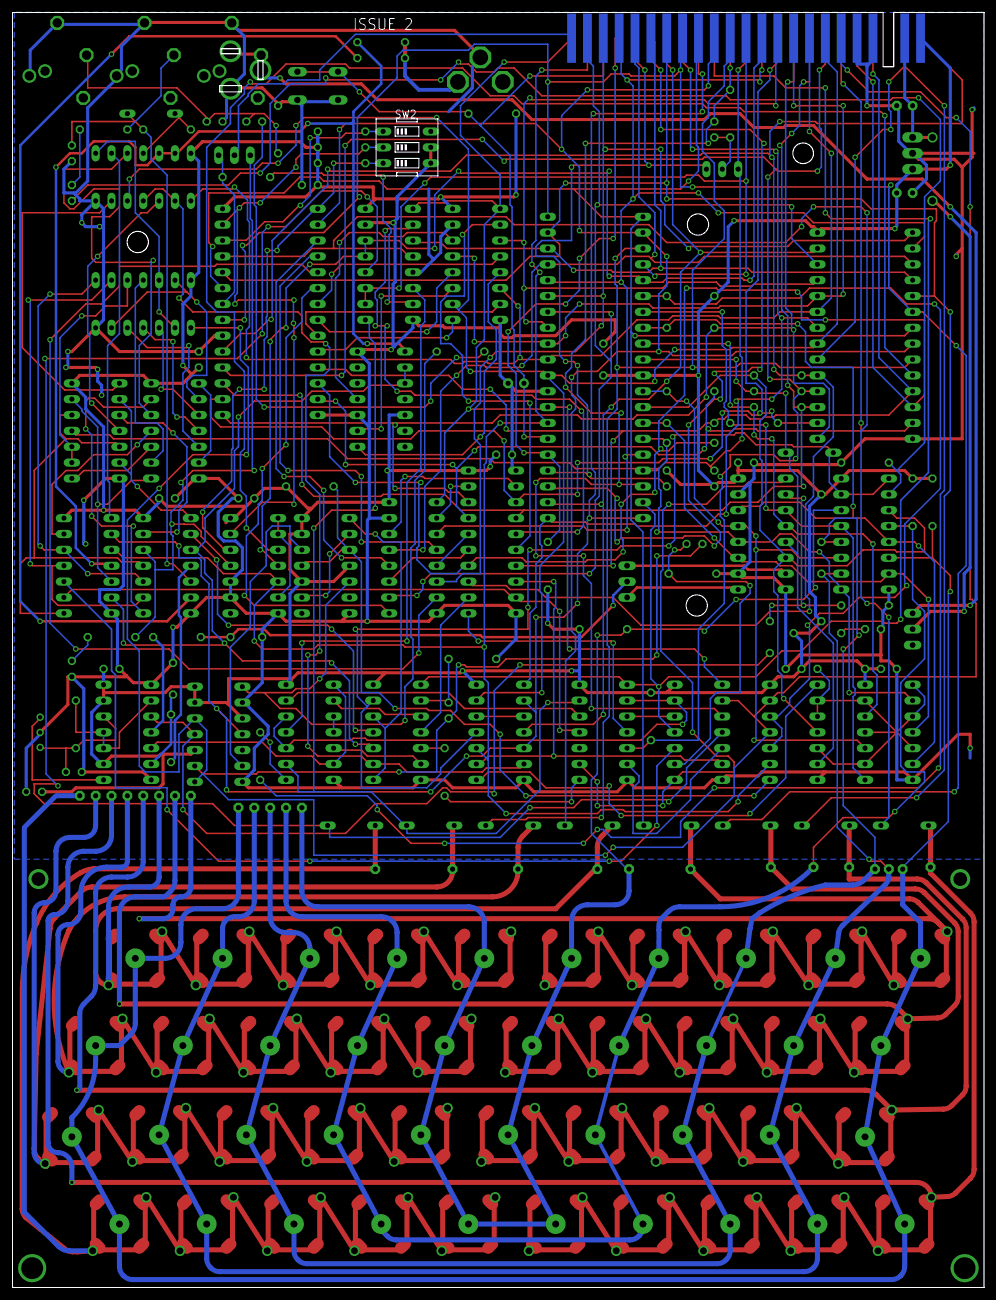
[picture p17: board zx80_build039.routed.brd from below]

Board: 2 copper layers, 155.6 x 204.2 mm, 231 parts (23 on the bottom side), 204 nets.

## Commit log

2023-03-29 added GERBER files
2023-07-17 build 039
    [COMPONENTS ZX80 1.2.1.xlsx, COMPONENTS ZX80 1.2.2.xlsx, ROMs 1.2.2.xlsx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]
